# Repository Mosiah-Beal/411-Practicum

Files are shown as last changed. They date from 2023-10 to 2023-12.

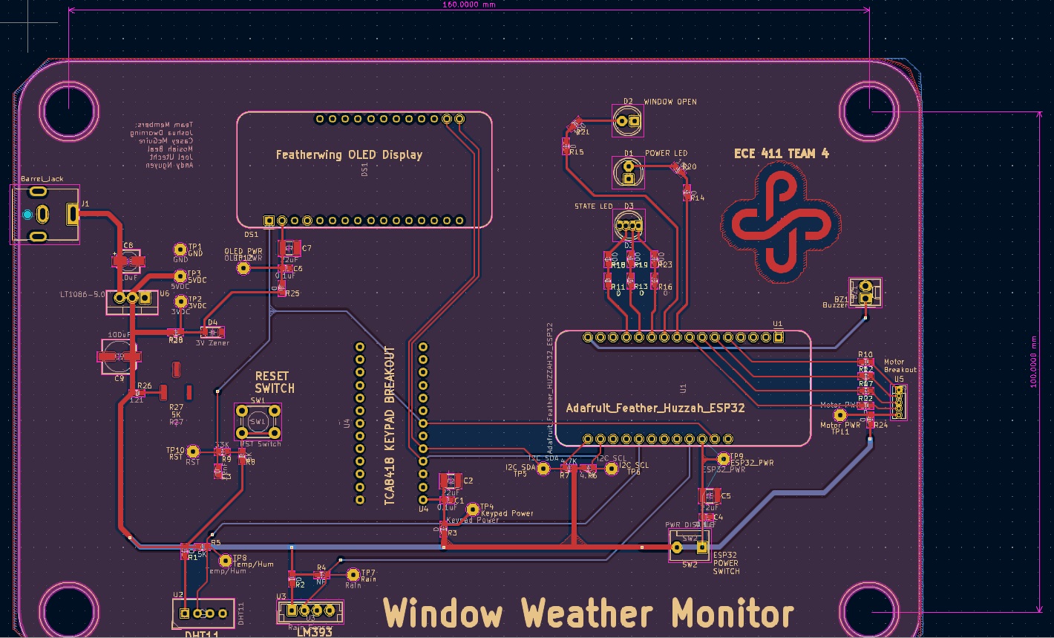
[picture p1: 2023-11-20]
PNG's and PDF's/Schematics and PCBs/PCBA Layout 2D.jpg

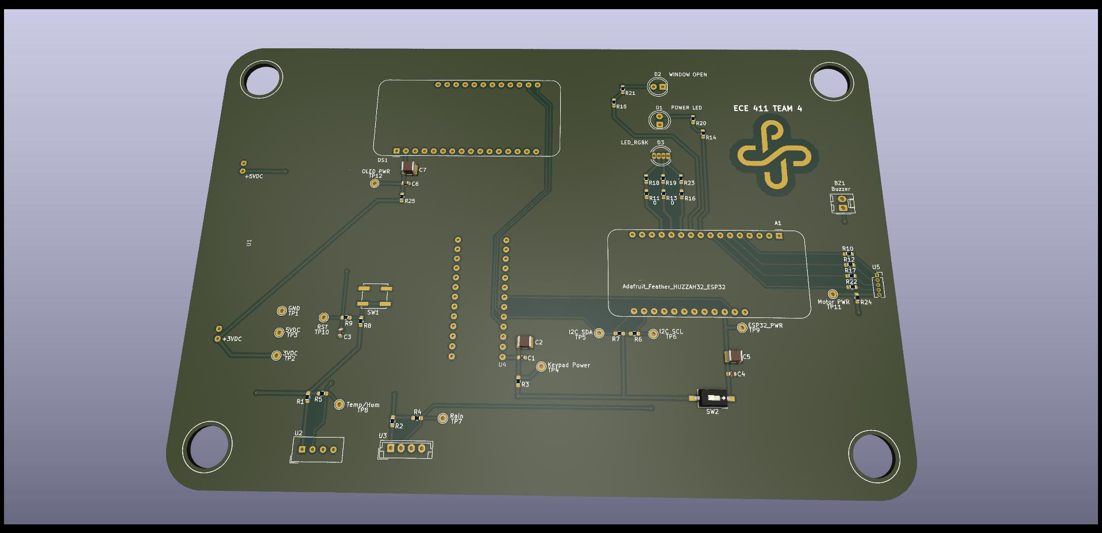
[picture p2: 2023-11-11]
PNG's and PDF's/Schematics and PCBs/window_weather_monitor_pcb.jpg

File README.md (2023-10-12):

# A weather monitor placed near a window
Portland State University Team 4 Practicum Project
Mosiah Beal,	Joshua Dworning,	Andy Nguyen,	Joel Utecht,	Casey McGuire

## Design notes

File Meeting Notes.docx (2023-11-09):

11/8/23

Meeting

Rough bleh of stuff we talked about.

- Question whether D0 Rain Sensor needs pull down or up resistor
- Added C4/C5 as decoupling capacitors on 3.3V Line
- Disconnected A0 of rain sensor from the ESP
- R2 is NP just in case a pull up is needed for D0 of rain sensor
- R1 is a pull up resistor
- R1 is pull up for DHT11 Sensor
- Need schematic to be compatible with DHT22 upgrade
- R15 added as a NP just in case a pull down resistor is needed
- R1 changed into a NP just in case a pull up resistor is needed instead.
- Individual GNDs added to specific pinout on schematic for cleaner look
- Keypad controls uses 4x4 Matrix connected to TCA8418 with communication using I2C
- TCA8418 is Soldered onto PCB
- ESP USB should not be connected when already powered otherwise
- Question whether a switch is needed for USB pin 26 on ESP
- R8/R9 is 0 just in case changes needed to be made
- D3 used to show if window is open
- D1 is LED RGB for environmental state. R G B
- Buzzeer output from ESP pin 16 to Buzzer.
- Question whether a universal RST switch is needed or just specific switch for ESP
- Maybe Display has its own discrete reset button?
  - Confirmed
- I2C/Display/ESP32 RST talk
- RST SW (Pin 7 I2C) global label made for reset
- Motor may need pull resistors. Not known yet. R3,4,5,7,12. Unknown since motor uses digital signals.
- Question whether ADC needs an input
  - Don’t think it matters**
- Layout question of having RESET connected via through hole so that it can jumper to enclosure
- BOM exact details questions asked.
- BOM Spit out by layout is ok.
  - Needs to be reformatted
- Stickers for keypad?
- USING SMD

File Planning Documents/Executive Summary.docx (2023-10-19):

Executive Summary

Problem Statement

Our team recently received feedback from customers in a self-responding poll reporting that they frequently leave their windows open and would like a solution to prevent water damage. The majority responded positively to our proposed product line, and among the price ranges provided, the majority favored a product that would cost no more than $200. Developing the Window Weather Monitor 30K is appropriate in today's market to satisfy this customer demand and increase our existing product lines.

Proposed Solution

The current market ranges up to $300, with most products priced in the $100 to $200 range. Our price point is expected to be $149. To satisfy both customer concerns and allow the company a competitive advantage, our product can offer:

- Sound-based alerts that will attract attention
- Sensors that will monitor for rain conditions and temperature
- A water-resistant enclosure to protect internal electronics
- A display that can report temperature

Final Thoughts and Next Steps

Our product stands out among market competitors because of the portability and more sensors.

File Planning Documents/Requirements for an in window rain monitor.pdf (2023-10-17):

Requirements for an in-window rain monitor.
- The monitor should be able to fit in an open window.
- The monitor should be able to be moved from one window to another.
- The monitor must be able to withstand getting wet from rain.
- The monitor must/should be able to detect when rain is falling on it,
- The monitor must be able to audibly alert the user when rain is detected.
- There must be a method to turn off the alert once it has been activated.
- The monitor should detect temperature.
- It should be able to detect humidity
- The monitor should display the detected temperature.
- The user should be able to manually program a desired temperature range.
- The monitor should be able to sound the audible alert when the detected temperature is outside the designated range.
- Should be able to run of battery power
- The monitor may include the capability of closing the window it is in.
- The monitor may have the capability to be programmed remotely.
- The monitor may have the capability to send alerts to the user’s cell phone.
- The monitor may have the capability to check weather status online.
- May have a rechargeable battery

—----------
- Must have speaker (piezo)
- Must have push buttons to disable alarm
- Must have rain sensor (lm393)
- Should have humidity and temperature sensor (dht11)
- Should have LED/LCD display to show weather condition
- May have stepper motor to ‘move’ window
- May use wifi/bluetooth module of ESP32

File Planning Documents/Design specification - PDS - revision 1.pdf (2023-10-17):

Weather monitor product design specifications
- ESP32 feather microcontroller, or ATmega328P
- Input sensor: DHT11 Temperature and humidity sensor module
- Input sensor: KY-022 IR receiver module
- Input: IR remote control - XIITIA
- Input sensor: LM393 raindrop sensor
- Output: LCD1602 display
- Output: LED
- Output: KY-012 active buzzer
- Output: 1 Motor Driver Board (e.g., Adafruit 2927)
- Output: 1 Stepper Motor (e.g., Amazon B00PNEQKC0)
- Power: USB
- Arduino IDE

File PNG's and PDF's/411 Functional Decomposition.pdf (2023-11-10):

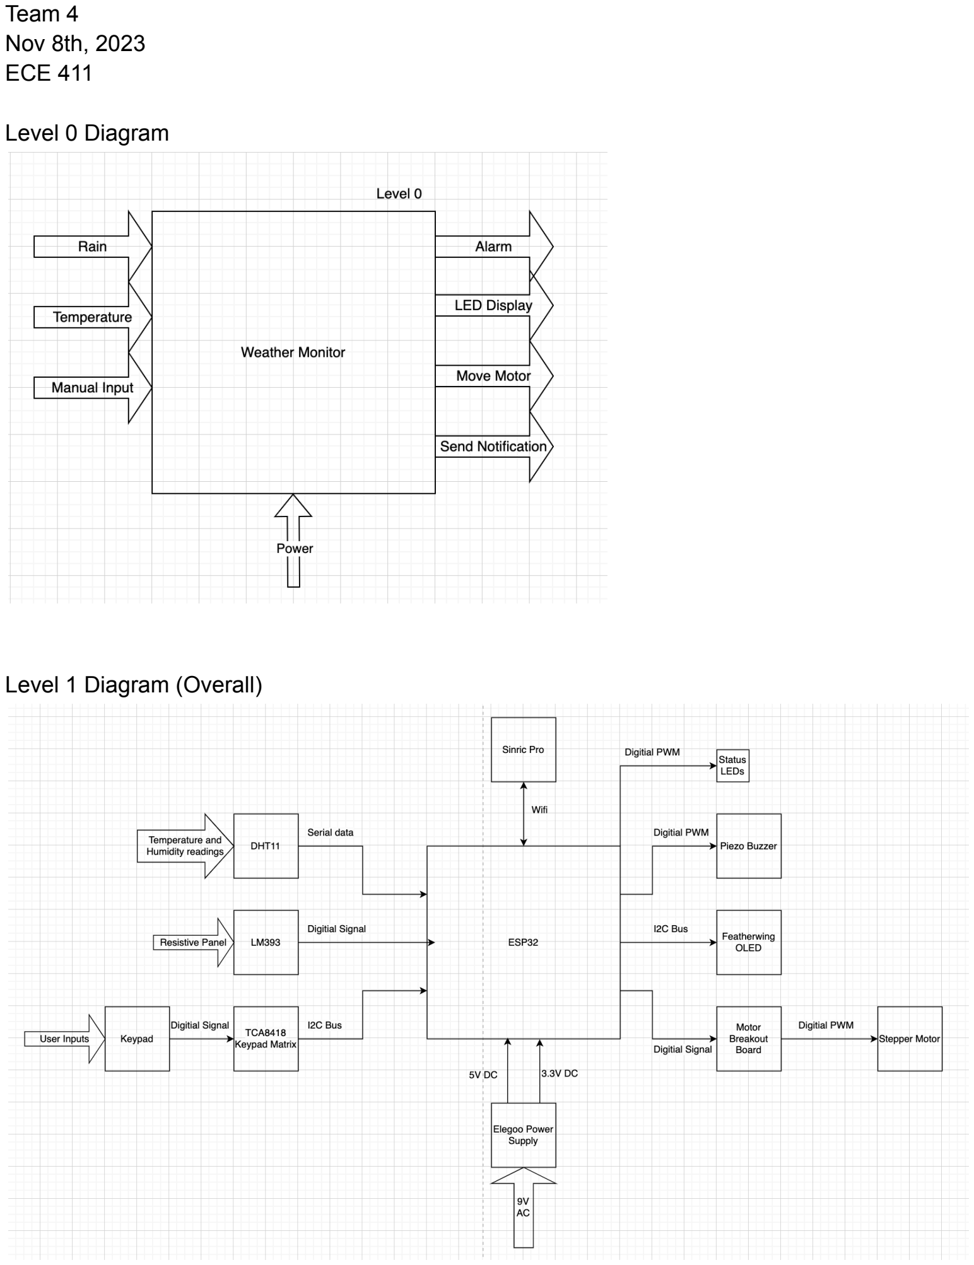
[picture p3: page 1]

Team 4
Nov 8th, 2023
ECE 411

Level 0 Diagram

Level 1 Diagram (Overall)

Power Supply Level 1 Diagram

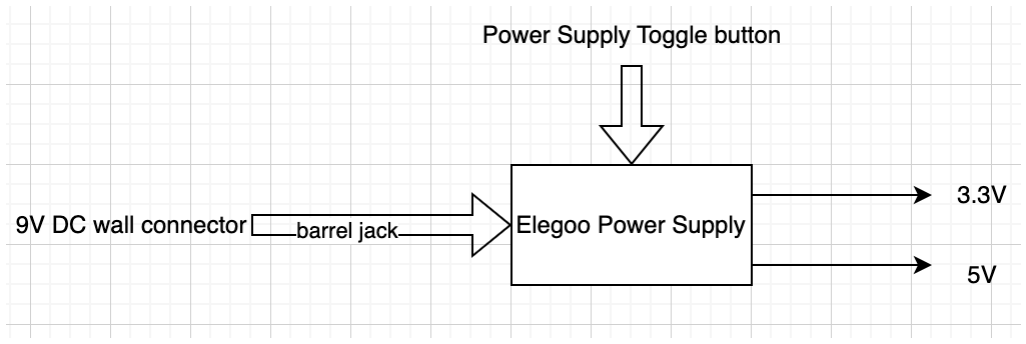
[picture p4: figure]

Module | Power Supply
Inputs | 9V DC: Wall adapter with a barrel jack that is plugged into the power supply Toggle button: A push switch to turn on/off the entire power supply
Outputs | 3.3V DC 5V DC
Functionality | It accepts 6.5-12V DC or USB input and has two independent channels that are configurable to output 3.3V or 5V DC. Can output current up to 700mA.

DHTxx Level 1 Diagram

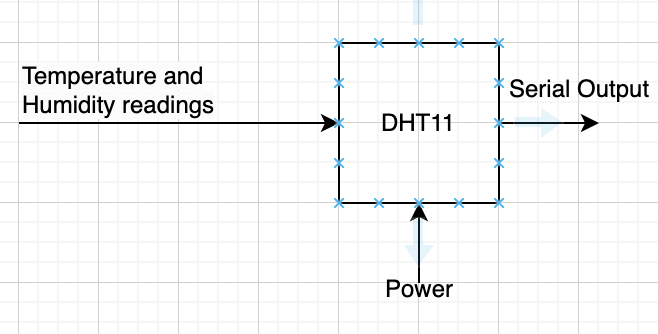
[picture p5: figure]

Module | DHT 11
Inputs | Environmental readings: temperature and humidity levels Power: 5V DC
Outputs | Digital signal: Serial output with a peak of 5V.
Functionality | Measures the temperature and humidity of nearby air, and sends data back through serial communication with the microcontroller. Requires a 5k pullup resistor on the data line.

LM393 / Rain sensor level 1 diagram

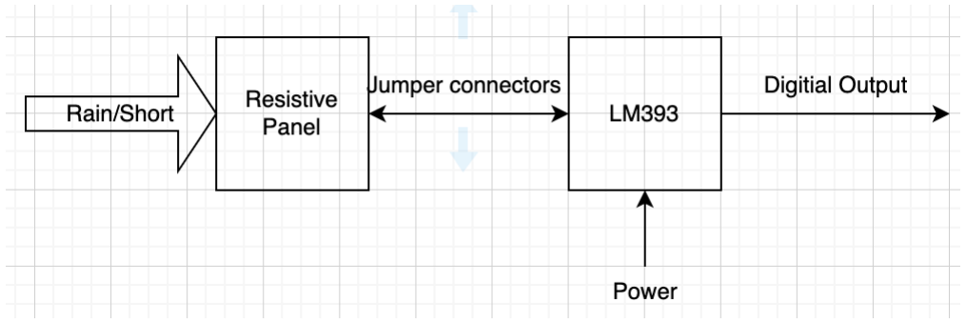
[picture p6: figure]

Module | LM393 + Rain sensor
Inputs | Voltage difference on resistive panel Power: 5V DC Potentiometer: built-in potentiometer that can adjusted to change the sensitivity/transition region of the digital output
Outputs | Digital signal: peak of 3.3V
Functionality | The resistive panel has two strips which are at different voltage levels. When it rains on the panel, a short is created between the strips, decreasing the voltage difference. The LM393 detects this difference and will output a digital signal if it is above a certain threshold. A 0 signifies it is raining while a 1 signifies that it isn’t raining.

Keypad Level 1 Diagram

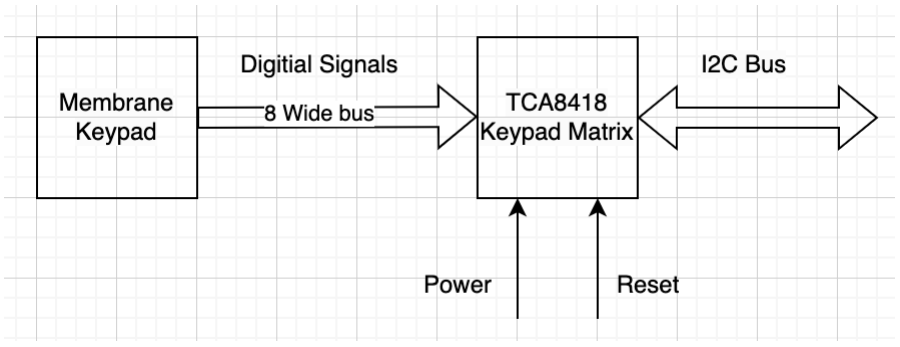
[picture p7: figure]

Module | Keypad Matrix breakout board
Inputs | Digital Signals: the row pins and column pins of the membrane keypad Power: 5V DC Reset switch
Outputs | I2C: Sends data about row and column pins to ESP32
Functionality | Used as a port expander since there were not enough pins available to be allocated to the keypad directly. It sends information about the row and column pins over I2C back to the ESP32. Has built-in 10k pullup resistors on SDA and SCL and is shifted to work with 3-5V logic.

LED Display Level 1 Diagram

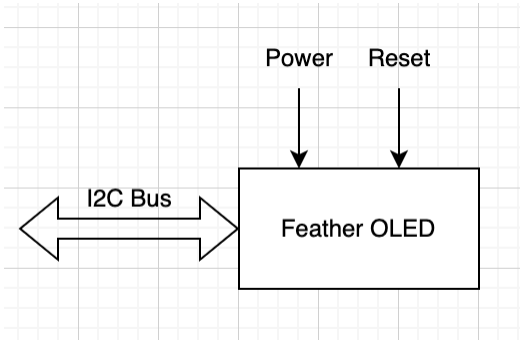
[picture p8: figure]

Module | FeatherWing OLED display
Inputs | I2C bus Reset switch Power: 3.3V DC
Outputs | OLED display updates visually
Functionality | Takes instructions/data from I2C and updates display accordingly. Should display temperature and humidity levels Has 2.2k pullup resistors on SDA and SCL, with 3V logic.

Stepper Motor Level 1 Diagram

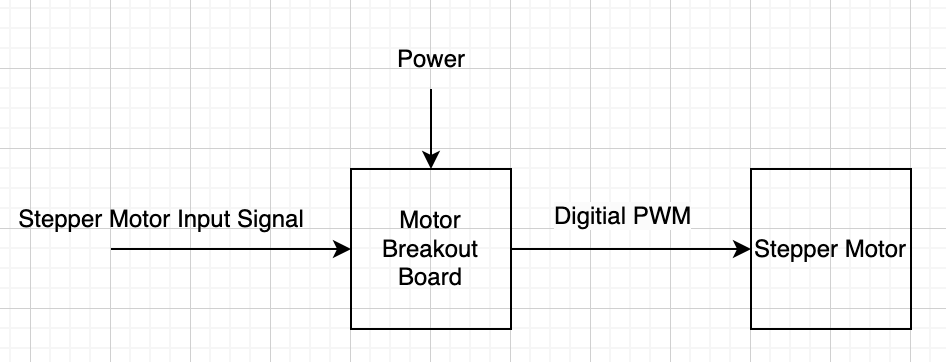
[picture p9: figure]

Module | Stepper motor breakout board
Inputs | Stepper Motor input Signal: digital signal containing the sequence of inputs to make the stepper motor take 1 step. Power: 5V DC
Outputs | Digital PWM: Digital signal which makes the stepper motor take the step
Functionality | The breakout board takes the input signals from the ESP32 and uses them to control the stepper motor. The voltage and current are supplied to the breakout board from the power supply, not the ESP32, which is then delivered to the stepper motor according to the input signals.

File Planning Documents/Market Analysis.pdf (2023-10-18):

The intended customers are people who need a reminder to close the windows during a weather

event.

Product competition for a window weather monitor is saturated. Competitors boast products that

have a motor that will automatically open and close windows and are capable of rain detection.

However, what separates our product from others is the inclusion of temperature and humdity

sensor modules, LED and LCD displays, power via USB, and audible noise alerts.

We could sell this for around $149. The reason for this price is due to the materials cost, labor,

and development. Market conditions for the competition will vary depending on the feature set

that is sought after, but similar products are ranging from $100-$300.

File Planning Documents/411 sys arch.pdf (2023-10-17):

Musts
Sense that it is raining
Sound an alarm

Shoulds
Sense temperature
Have led display status
Have analog input (buttons) for input

Mays
Close the window
Send mobile alerts

—---
Level 0
Ins
Temperature : Analog I/O
Rain : Analog I/O
Programming ESP32: USB cable Power - bullet jack or battery: Analog

Outs
Display: I2C
Buttons : Analog
Speaker alarm : PWM

Maybe:
Phone: wifi/bluetooth
Motor: I2C

—---
Level 1
Temperature, Rain, Buttons, speaker Sensor - does sensing
Sends analog voltage back to processor

Motor and Display : I2C, expand separately

Phone: whatever bluetooth options are chosen

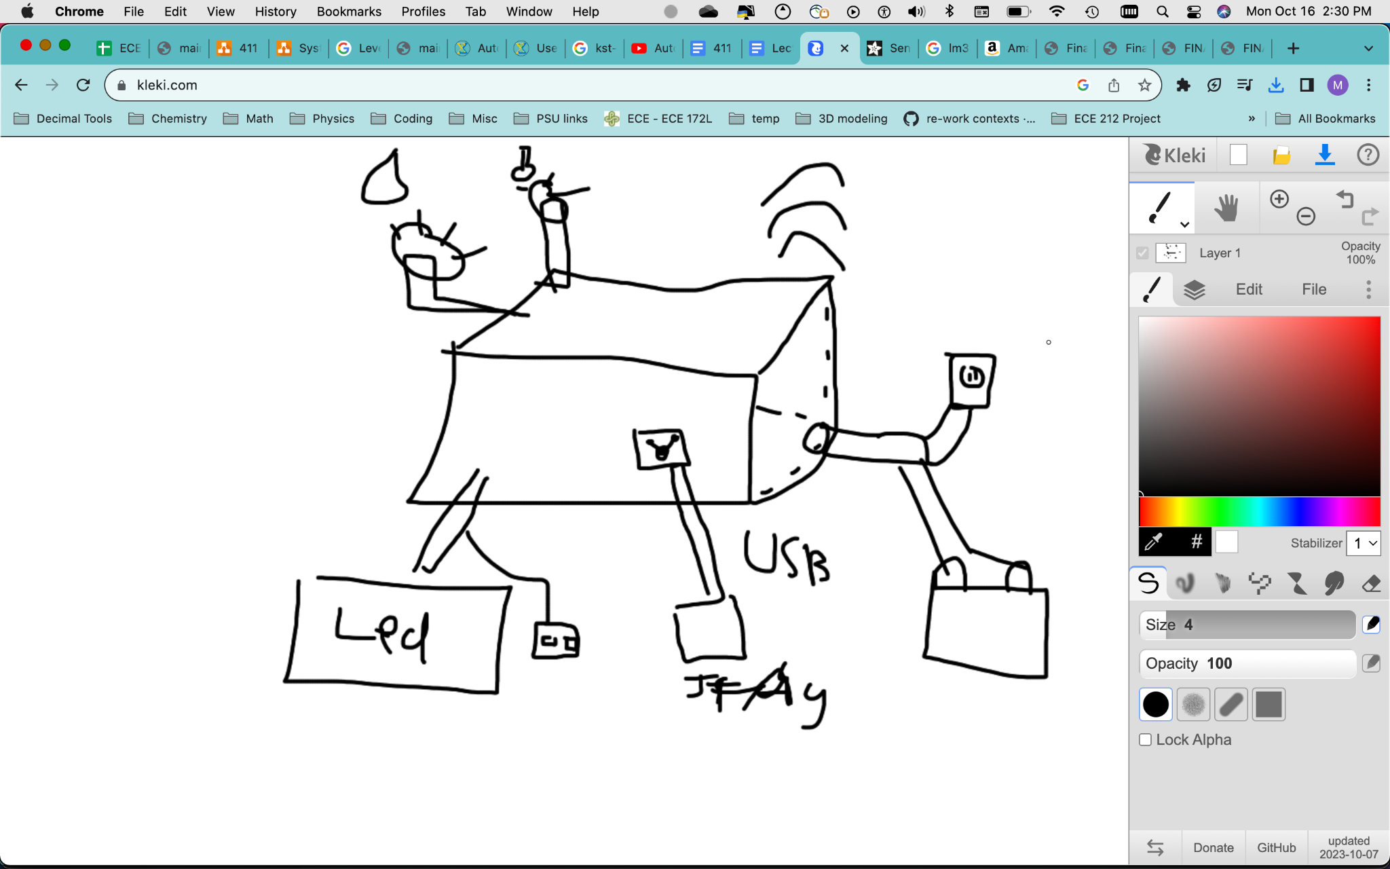
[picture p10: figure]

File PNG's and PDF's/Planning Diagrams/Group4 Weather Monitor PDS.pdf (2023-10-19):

## Executive Summary

### Problem Statement

Our team recently received feedback from customers in a self-responding poll reporting that they frequently leave their windows open and would like a solution to prevent water damage. The majority responded positively to our proposed product line, and among the price ranges provided, the majority favored a product that would cost no more than $200. Developing the Window Weather Monitor 30K is appropriate in today's market to satisfy this customer demand and increase our existing product lines.

### Proposed Solution

The current market ranges up to $300, with most products priced in the $100 to $200 range. Our price point is expected to be $149. To satisfy both customer concerns and allow the company a competitive advantage, our product can offer:
- Sound-based alerts that will attract attention
- Sensors that will monitor for rain conditions and temperature
- A water-resistant enclosure to protect internal electronics
- A display that can report temperature

### Final Thoughts and Next Steps

Our product stands out among market competitors because of the portability and more sensors.

Market:
The intended customers are people who need a reminder to close the windows during a weather event.

Product competition for a window weather monitor is saturated. Competitors boast products that have a motor that will automatically open and close windows and are capable of rain detection. However, what separates our product from others is the inclusion of temperature and humidity sensor modules, LED and LCD displays, power via USB, and audible noise alerts.

We could sell this for around $149. The reason for this price is due to the materials cost, labor, research, and development. Market conditions for the competition will vary depending on the feature set that is sought after, but similar products range from $100-$300.

Requirements:
For our product to meet the needs of our target market it must meet the following criteria. It must be able to detect when it is raining and audibly alert the user when rain is present. There must be a way to manually turn off the audible alert. There should also be a visual alert. The monitor must also be able to withstand repeated exposure to rain.

The monitor should also be able to detect and visually display the current temperature and humidity level. The monitor should allow the user to manually program a desired temperature range and audibly alert the user when the detected temperature is outside the programmed range. The monitor should have an internal power supply that may be rechargeable. The monitor should be able to sit in an open window or be affixed to the exterior near the window. The monitor should be able to be moved from one window to another.
If time and budget allow the monitor may also include some combination of the following features. The monitor may have the capability to close the window it is used in. It may also allow for remote programming and the ability to silence the alerts. It may include connectivity capabilities to monitor weather conditions from an online source and to send window closure alerts to the user's cell phone.

Architecture:

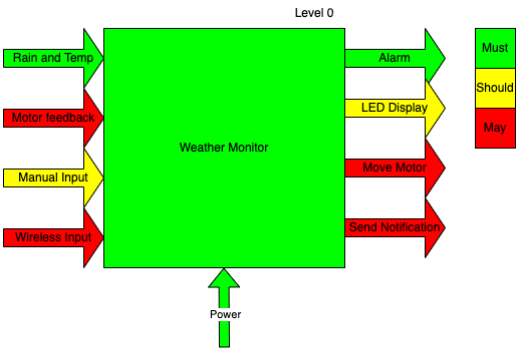
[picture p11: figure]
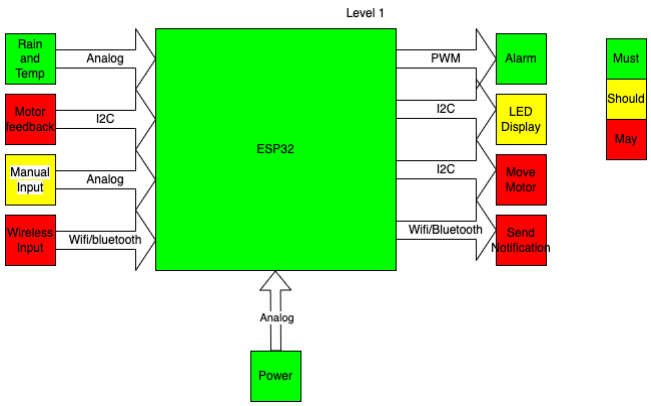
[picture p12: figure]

Design:

Weather monitor product design specifications
- ESP32 feather microcontroller, or ATmega328P
- Input sensor: DHT11 Temperature and humidity sensor module
- Input sensor: KY-022 IR receiver module
- Input: IR remote control - XIITIA
- Input sensor: LM393 raindrop sensor
- Output: LCD1602 display
- Output: LED
- Output: KY-012 active buzzer
- Output: 1 Motor Driver Board (e.g., Adafruit 2927)
- Output: 1 Stepper Motor (e.g., Amazon B00PNEQKC0)
- Power: USB
- Arduino IDE

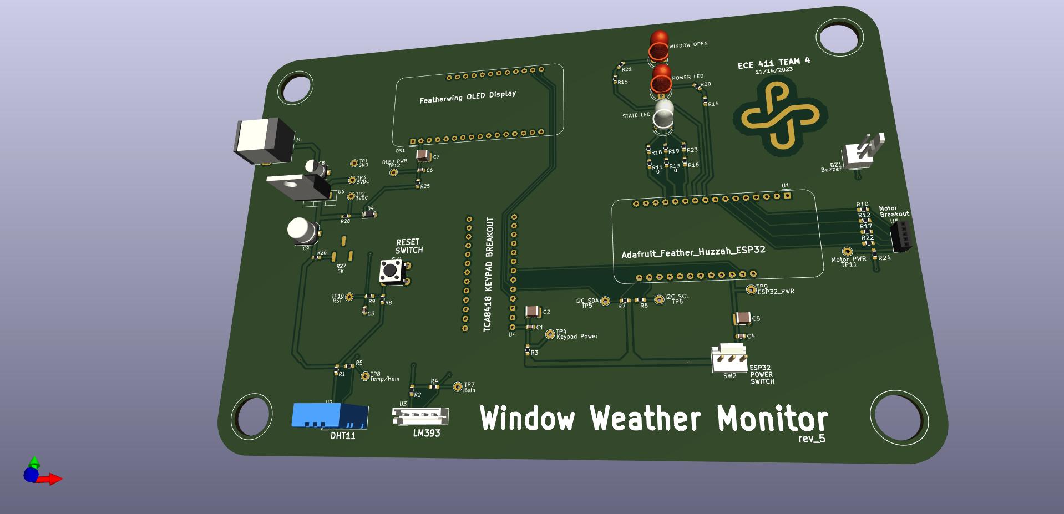
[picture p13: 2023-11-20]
PNG's and PDF's/Schematics and PCBs/PCBA Layout 3D.jpg

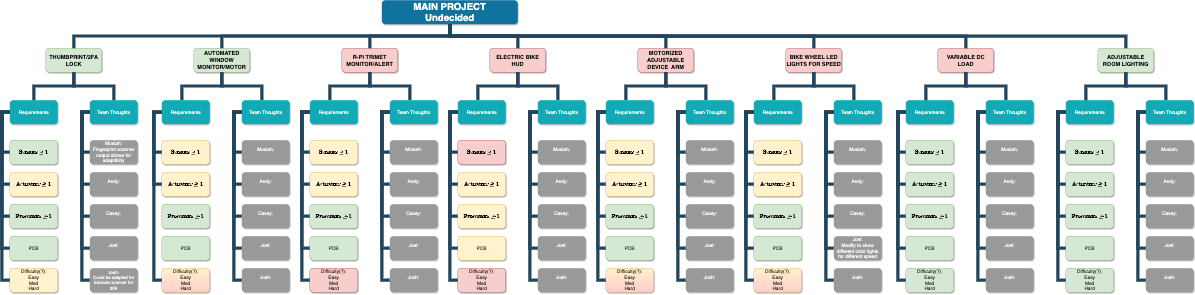
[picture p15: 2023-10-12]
PNG's and PDF's/Planning Diagrams/Zoomed_out_Tree.drawio.png

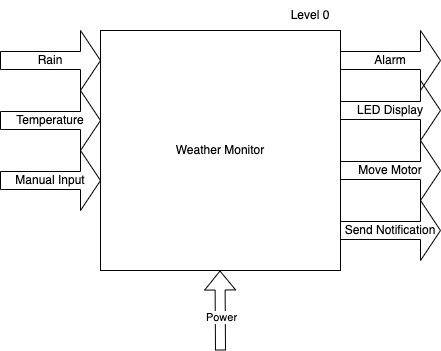
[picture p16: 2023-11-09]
Planning Documents/Level0_Diagram.drawio.png

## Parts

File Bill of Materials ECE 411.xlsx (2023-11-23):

Bill Of Materials for: [TEAM 4] [Window Weather Monitor]
Last modified: [11/8/23]
PCB version: [PCB VERSION #1]
BOM revision: [BOM REVISION #1] |  |  |  | P/NP | = Place/Not Place (components marked NP are not stuffed on the board)
Item | Qty | Part References | Value | P/NP | Mfg | Mfg PN | Description | Dist | Dist Part Number | Cost Ea. | Cost Total | Received (Y/N) | Received QTY
1 | 1 | BZ1 |  | P | Mallory Sonalert | AST1341MCTRQ (https://www.digikey.com/en/products/detail/mallory-sonalert-products-inc/AST1341MCTRQ/11567574) | BUZZER PIEZO 5V 13X13MM SMD | Digi-Key | 458-AST1341MCTRQCT-ND | $2.06 | $2.06 | Y | 3
2 | 3 | C1, C4, C6 | 0.1uF | P | Kemet | C0603C104K8RAC7867 | CAP CER 0.1UF 10V X7R 0603 | Digi-Key | 399-C0603C104K8RAC7867TR-ND (https://www.digikey.com/en/products/detail/kemet/C0603C104K8RAC7867/411094) | $0.10 | $0.20 | N
3 | 3 | C2, C5, C7 | 22uF | P | Samsung | CL32B226KPJVPNE | CAP CER 22UF 10V X7R 1210 | Digi-Key | 1276-CL32B226KPJVPNETR-ND (https://www.digikey.com/en/products/detail/samsung-electro-mechanics/CL32B226KPJVPNE/11487743) | $0.74 | $2.22 | N
4 | 1 | C3 | 0.022uF | P | Wurth Elektronik | 885012206016 | CAP CER 0.022UF 10V X7R 0603 | Digi-Key | 732-7935-2-ND (https://www.digikey.com/en/products/detail/w%C3%BCrth-elektronik/885012206016/5453790) | $0.10 | $0.40 | N
5 | 1 | C8 | 100UF | P | Panasonic | EEE-HA1A101WP | CAP ALUM 100UF 10V | Digi-Key | PCE4169TR-ND (https://www.digikey.com/en/products/detail/panasonic-electronic-components/EEE-HA1A101WP/814141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) | $0.42 | $2.10 | N | 0
6 | 1 | C9 | 10UF | P | Panasonic | EEE-1CA100SR | CAP ALUM 10UF 16V | Digi-Key | PCE3878TR-ND (https://www.digikey.com/en/products/detail/panasonic-electronic-components/EEE-1CA100SR/766045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) | $0.32 | $1.92 | N
7 | 1 | D1 | RED | P | Marktech Optoelectronics | MT4118-HR-A | 5MM LED RED DIFFUSED | Digi-Key | 1125-1188-ND (https://www.digikey.com/en/products/detail/marktech-optoelectronics/MT4118-HR-A/4214622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) | $0.32 | $0.32 | Y | 3
8 | 1 | D2 | GREEN | P | Marktech Optoelectronics | MT2118-G-A | 5MM LED GREEN DIFFUSED | Digi-Key | 1125-1184-ND (https://www.digikey.com/en/products/detail/marktech-optoelectronics/MT2118-G-A/4214619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) | $0.31 | $0.31 | Y | 3
9 | 1 | D3 | RGBK | P | Inolux | HV-5RGB60 | 5MM LED RGBK DIFFUSED | Digi-Key | 1830-1014-ND (https://www.digikey.com/en/products/detail/inolux/HV-5RGB60/7604616?s=N4IgTCBcDaIBIDUC0BWASgcQEIDYAMIAugL5A) | $1.00 | $1.00 | Y | 2
10 | 1 | D4 | 3V | P | Micro Commercial Co | MMSZ4684-TP | DIODE ZENER 3.3V 500MW SOD123 | Digi-Key | MMSZ4684-TPMSTR-ND (https://www.digikey.com/en/products/detail/micro-commercial-co/MMSZ4684-TP/2345538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) | $0.12 | $0.12 | N
11 | 1 | DS1 |  | P | Adafruit | 128x4 OLED | OLED DISPLAY | Adafruit | 2900 (https://www.adafruit.com/product/2900) | $14.95 | $14.95 | Y | 3
12 | 1 | J1 |  | P | CUI Devices | PJ-063AH | CONN PWR BARREL JACK | Digi-Key | CP-063AH-ND (https://www.digikey.com/en/products/detail/cui-devices/PJ-063AH/2161208?s=N4IgTCBcDaIAoCkC0AGAbAZgIIAkQF0BfIA) | $1.55 | $1.55 | Y | 5
13 | 1 | K1 |  | P | Parallax | 4X4MEMKYPD | 4X4 MEMBRANE KEYPAD | Parallax | 27899 (https://www.parallax.com/product/4x4-matrix-membrane-keypad/) | $9.95 | $9.95 | Y | 2
14 | 14 | R1, R2, R3, R10, R11, R12, R13, R14, R15, R16, R17, R22, R24, R25 | 0 Ohm | P | Stackpole Elec. Inc. | RMCF0603ZT0R00 | RES 0 OHM JUMPER 1/10W 0603 | Digi-Key | RMCF0603ZT0R00TR-ND (https://www.digikey.com/en/products/detail/stackpole-electronics-inc/RMCF0603ZT0R00/1756908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) | $0.10 | $1.40 | N
15 | 1 | R4 | 5K Ohm | NP | Yageo | RT0603BRE075KL | RES 5K OHM 1/10W 0603 | Digi-Key | 13-RT0603BRE075KLTR-ND (https://www.digikey.com/en/products/detail/yageo/RT0603BRE075KL/7708365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) | $0.39 | $0.39 | N
16 | 2 | R5, R8 | 5K Ohm | P | Yageo | RT0603BRE075KL | RES 5K OHM 1/10W 0603 | Digi-Key | 13-RT0603BRE075KLTR-ND (https://www.digikey.com/en/products/detail/yageo/RT0603BRE075KL/7708365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) | $0.39 | $0.78 | N
17 | 2 | R6, R7 | 4.7 kOhm | P | KOA Speer Electronics | RK73B1JTTD472J | RES 4.7K OHM 1/10W 0603 | Digi-Key | 2019-RK73B1JTTD472JTR-ND (https://www.digikey.com/en/products/detail/koa-speer-electronics-inc/RK73B1JTTD472J/9844699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) | $0.10 | $0.20 | N
18 | 1 | R9 | 33 kOhm | P | Stackpole Elec. Inc. | RMCF0603FT33K0 | RES 33K OHM 1/10W 0603 | Digi-Key | RMCF0603FT33K0TR-ND (https://www.digikey.com/en/products/detail/stackpole-electronics-inc/RMCF0603FT33K0/1760742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) | $0.10 | $0.10 | N
19 | 5 | R18, R19, R20, R21, R23 | 100 Ohm | P | Stackpole Elec. Inc. | RMCF0603FT100R | RES 100 OHM 1/10W 0603 | Digi-Key | RMCF0603FT100RTR-ND (https://www.digikey.com/en/products/detail/stackpole-electronics-inc/RMCF0603FT100R/1761113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) | $0.10 | $0.50 | N
20 | 1 | R26 | 121 Ohm | P | Stackpole Elec. Inc. | RMCF0603FT121R | RES 121 OHM 1/10W 0603 | Digi-Key | RMCF0603FT121RTR-ND (https://www.digikey.com/en/products/detail/stackpole-electronics-inc/RMCF0603FT121R/1761217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) | $0.10 | $0.10 | N
21 | 1 | R27 | 5 kOHM | P | TT Electronics | 84WR5KLFTR | TRIMMER 5K OHM 0.25W SMD | Digi-Key | 987-1810-2-ND (https://www.digikey.com/en/products/detail/tt-electronics-bi/84WR5KLFTR/6155682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) | $3.36 | $3.36 | N
22 | 1 | R28 | 430 Ohm | P | Stackpole Elec. Inc. | RMCF0603FT430R | RES 430 OHM 1/10W 0603 | Digi-Key | RMCF0603FT430RTR-ND (https://www.digikey.com/en/products/detail/stackpole-electronics-inc/RMCF0603FT430R/1761190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) | $0.10 | $0.10 | N
23 | 1 | SW1 |  | P | DAOKI | SPST THT SW | 6MM MOMENTARY SWITCH THT | Amazon | DAOKITHTPB (https://www.amazon.com/DAOKI-Miniature-Momentary-Tactile-Quality/dp/B01CGMP9GY?hvadid=80676721524207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) | $0.05 | $0.05 | Y | 5
24 | 1 | SW2 |  | P | C&K | TS02CQE | SWITCH SLIDE SPST 1A 120V | Digi-Key | CKN10666-ND (https://www.digikey.com/en/products/detail/c-k/TS02CQE/3755397?s=N4IgTCBcDaICoGUAMYDCBFAoiAugXyA) | $7.76 | $7.76 | Y | 100
25 | 1 | U1 |  | P | Adafruit | ESP32-HUZZAH | Adafruit ESP32 Huzzah Feather Board | Adafruit | 3405 (https://www.adafruit.com/product/3405) | $19.95 | $19.95 | Y | 2
26 | 1 | U2 |  | P | Adafruit | DHT22 | TEMP/HUM SENSOR | Adafruit | 385 (https://www.adafruit.com/product/385) | $9.95 | $9.95 | Y | 2
27 | 1 | U3 |  | P | HiLetgo | LM393 | LM393 MOISTURE SENSOR | Amazon | HILETGO-LM393 | $2.20 | $2.20 | Y | 4
28 | 1 | U4 |  | P | Adafruit | TCA8418 | KEYPAD EXANDER BREAKOUT | Adafruit | 4918 (https://www.adafruit.com/product/4918) | $5.95 | $5.95 | Y | 3
29 | 1 | U5 |  | P | ULN | ULN2003 | STEPPER MOTOR DRIVE BREAKOUT | Amazon | ULN2003 (https://www.amazon.com/ULN2003-Controller-Stepping-Electric-Control/dp/B07P5C2KWX) | $2.30 | $2.30 | Y | 1
30 | 1 | U6 |  | P | Analog Devices | LT1086CT#PBF | IC REG LIN POS ADJ 1.5A TO220-3 | Digi-Key | 505-LT1086CT#PBF-ND (https://www.digikey.com/en/products/detail/analog-devices-inc/LT1086CT-PBF/891238) | $6.29 | $6.29 | Y | 5
 |  |  |  |  |  |  |  |  |  | TOTAL: | $98.48
VERSION INFO
Rev |  | Date |  | Notes
1.0r0 |  | 2023-11-07 |  | Initial BOM. Not everything chosen but mostly there.
2.0r0 |  | 2023-11-13 |  | Updated BOM. Almost everything chosen.
2.0r1 |  | 2023-11-22 |  | Updated BOM to add part values where applicable. Also added received section.

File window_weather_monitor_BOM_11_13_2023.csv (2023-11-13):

Source: | C:\Users\jdworning\Documents\KiCad\ECE411_Practicum\window_weather_monitor\window_weather_monitor.kicad_sch
Date: | 11/13/2023 11:16:47 AM
Tool: | Eeschema 7.0.8
Generator: | C:\Program Files\KiCad\7.0\bin\scripting\plugins/bom_csv_grouped_by_value.py
Component Count: | 65
Collated Components:
Item | Qty | Reference(s) | Value | LibPart | Footprint | Datasheet | DNP | Color | MFG PN | Notes | Part Link | Pinout
1 | 1 | BZ1 | Buzzer | Device:Buzzer | Connector_Molex:Molex_KK-254_AE-6410-02A_1x02_P2.54mm_Vertical | ~ |  |  | N/A
2 | 3 | C1, C4, C6 | 0.1uF | Device:C_Small | Capacitor_SMD:C_0603_1608Metric | ~ |  |  | C0603C104K8RAC7867 |  | https://www.digikey.com/en/products/detail/kemet/C0603C104K8RAC7867/411094
3 | 3 | C2, C5, C7 | 22uF | Device:C_Small | Capacitor_SMD:C_1210_3225Metric | ~ |  |  | CL32B226KPJVPNE |  | https://www.digikey.com/en/products/detail/samsung-electro-mechanics/CL32B226KPJVPNE/11487743
4 | 1 | C3 | 22nF | Device:C_Small | Capacitor_SMD:C_0603_1608Metric | ~ |  |  | CL05B223KP5NNNC |  | https://www.digikey.com/en/products/detail/samsung-electro-mechanics/CL05B223KP5NNNC/3887196
5 | 1 | C8 | 10uF | Device:C_Polarized_Small_US | Capacitor_SMD:CP_Elec_4x5.4 | ~ |  |  | EEE-HA1A101WP |  | https://www.digikey.com/en/products/detail/panasonic-electronic-components/EEE-HA1A101WP/814141
6 | 1 | C9 | 100uF | Device:C_Polarized_Small_US | Capacitor_SMD:C_Elec_6.3x5.8 | ~ |  |  | EEE-1CA100SR |  | https://www.digikey.com/en/products/detail/panasonic-electronic-components/EEE-1CA100SR/766045
7 | 1 | D1 | POWER LED | Device:LED | LED_THT:LED_D5.0mm | ~ |  | RED | MT4118-HR-A |  | https://www.digikey.com/en/products/detail/marktech-optoelectronics/MT4118-HR-A/4214622
8 | 1 | D2 | WINDOW OPEN | Device:LED | LED_THT:LED_D5.0mm | ~ |  |  | MT2118-G-A |  | https://www.digikey.com/en/products/detail/marktech-optoelectronics/MT2118-G-A/4214619
9 | 1 | D3 | LED_RGBK | Device:LED_RGBK | LED_THT:LED_D5.0mm-4_RGB | ~ |  |  | HV-5RGB60 |  | https://www.digikey.com/en/products/detail/inolux/HV-5RGB60/7604616
10 | 1 | D4 | 3V Zener | Device:D_Zener | Diode_SMD:D_SOD-123 | ~ |  |  | MMSZ4684-TP |  | https://www.digikey.com/en/products/detail/micro-commercial-co/MMSZ4684-TP/2345538
11 | 1 | DS1 | ~ | my_library:Display-OLED-FeatherWing | Module:Adafruit_Feather |  |  |  | 128x4 OLED
12 | 1 | J1 | Barrel_Jack | Connector:Barrel_Jack | Connector_BarrelJack:BarrelJack_CUI_PJ-063AH_Horizontal | ~ |  |  | PJ-063AH |  | https://www.digikey.com/en/products/detail/cui-devices/PJ-063AH/2161208
13 | 1 | K1 | 4x4_Matrix_Keypad | my_library:4x4_Matrix_Keypad
14 | 14 | R1, R2, R3, R10, R11, R12, R13, R14, R15, R16, R17, R22, R24, R25 | 0 | Device:R | Resistor_SMD:R_0603_1608Metric_Pad0.98x0.95mm_HandSolder | ~ |  |  | RMCF0603ZT0R00 |  | https://www.digikey.com/en/products/detail/stackpole-electronics-inc/RMCF0603ZT0R00/1756908
15 | 1 | R4 | NP | Device:R | Resistor_SMD:R_0603_1608Metric_Pad0.98x0.95mm_HandSolder | ~ |  |  | RMCF0603ZT0R00 |  | https://www.digikey.com/en/products/detail/stackpole-electronics-inc/RMCF0603ZT0R00/1756908
16 | 2 | R5, R8 | 5K | Device:R | Resistor_SMD:R_0603_1608Metric_Pad0.98x0.95mm_HandSolder | ~ |  |  | RT0603BRE075KL | 5K | https://www.digikey.com/en/products/detail/yageo/RT0603BRE075KL/7708365
17 | 2 | R6, R7 | 4.7K | Device:R | Resistor_SMD:R_0603_1608Metric_Pad0.98x0.95mm_HandSolder | ~ |  |  | RK73B1JTTD472J | 4.7K | https://www.digikey.com/en/products/detail/koa-speer-electronics-inc/RK73B1JTTD472J/9844699
18 | 1 | R9 | 33K | Device:R | Resistor_SMD:R_0603_1608Metric_Pad0.98x0.95mm_HandSolder | ~ |  |  | RMCF0603FT33K0 |  | https://www.digikey.com/en/products/detail/stackpole-electronics-inc/RMCF0603FT33K0/1760742
19 | 5 | R18, R19, R20, R21, R23 | 100 | Device:R | Resistor_SMD:R_0603_1608Metric_Pad0.98x0.95mm_HandSolder | ~ |  |  | RMCF0603FT100R |  | https://www.digikey.com/en/products/detail/stackpole-electronics-inc/RMCF0603FT100R/1761113
20 | 1 | R26 | 121 | Device:R | Resistor_SMD:R_0603_1608Metric_Pad0.98x0.95mm_HandSolder | ~ |  |  | RMCF0603FT121R |  | https://www.digikey.com/en/products/detail/stackpole-electronics-inc/RMCF0603FT121R/1761217
21 | 1 | R27 | 5K | Device:R_Variable | my_library:5K Trim Pot | ~ |  |  | 84WR5KLFTR |  | https://www.digikey.com/en/products/detail/tt-electronics-bi/84WR5KLFTR/6155682
22 | 1 | R28 | 430 | Device:R | Resistor_SMD:R_0603_1608Metric_Pad0.98x0.95mm_HandSolder | ~ |  |  | RMCF0603FT430R |  | https://www.digikey.com/en/products/detail/stackpole-electronics-inc/RMCF0603FT430R/1761190
23 | 1 | SW1 | RST Switch | Switch:SW_Push | Button_Switch_THT:SW_PUSH_6mm | ~ |  |  | DAOKI SPST |  | https://www.amazon.com/DAOKI-Miniature-Momentary-Tactile-Quality/dp/B01CGMP9GY?hvadid=80676721524207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
24 | 1 | SW2 | PWR DISABLE | Switch:SW_SPST | Connector:FanPinHeader_1x03_P2.54mm_Vertical | ~ |  |  | TS02CQE |  | https://www.digikey.com/en/products/detail/c-k/TS02CQE/3755397
25 | 1 | TP1 | GND | Connector:TestPoint_Small | my_library:TestPoint_THTPad_D2.0mm_Drill1.0mm | ~
26 | 1 | TP2 | 3VDC | Connector:TestPoint_Small | my_library:TestPoint_THTPad_D2.0mm_Drill1.0mm | ~
27 | 1 | TP3 | 5VDC | Connector:TestPoint_Small | my_library:TestPoint_THTPad_D2.0mm_Drill1.0mm | ~
28 | 1 | TP4 | Keypad Power | Connector:TestPoint_Small | my_library:TestPoint_THTPad_D2.0mm_Drill1.0mm | ~
29 | 1 | TP5 | I2C SDA | Connector:TestPoint_Small | my_library:TestPoint_THTPad_D2.0mm_Drill1.0mm | ~
30 | 1 | TP6 | I2C SCL | Connector:TestPoint_Small | my_library:TestPoint_THTPad_D2.0mm_Drill1.0mm | ~
31 | 1 | TP7 | Rain | Connector:TestPoint_Small | my_library:TestPoint_THTPad_D2.0mm_Drill1.0mm | ~
32 | 1 | TP8 | Temp/Hum | Connector:TestPoint_Small | my_library:TestPoint_THTPad_D2.0mm_Drill1.0mm | ~
33 | 1 | TP9 | ESP32_PWR | Connector:TestPoint_Small | my_library:TestPoint_THTPad_D2.0mm_Drill1.0mm | ~
34 | 1 | TP10 | RST | Connector:TestPoint_Small | my_library:TestPoint_THTPad_D2.0mm_Drill1.0mm | ~
35 | 1 | TP11 | Motor PWR | Connector:TestPoint_Small | my_library:TestPoint_THTPad_D2.0mm_Drill1.0mm | ~
36 | 1 | TP12 | OLED PWR | Connector:TestPoint_Small | my_library:TestPoint_THTPad_D2.0mm_Drill1.0mm | ~
37 | 1 | U1 | Adafruit_Feather_HUZZAH32_ESP32 | MCU_Module:Adafruit_Feather_HUZZAH32_ESP32 | Module:Adafruit_Feather | https://cdn-learn.adafruit.com/downloads/pdf/adafruit-huzzah32-esp32-feather.pdf
38 | 1 | U2 | DHT11 | Sensor:DHT11 | Sensor:Aosong_DHT11_5.5x12.0_P2.54mm | http://akizukidenshi.com/download/ds/aosong/DHT11.pdf |  |  |  |  |  | S. -> P1
39 | 1 | U3 | Rain Sensor | my_library:LM393_Rain_Sensor | Connector_JST:JST_EH_B4B-EH-A_1x04_P2.50mm_Vertical | ~
40 | 1 | U4 | ~ | my_library:TCA8418_Keypad_/_GPIO_Extension | my_library:TCA8418
41 | 1 | U5 | ~ | my_library:Motor_Control_IO | Connector_PinSocket_1.27mm:PinSocket_1x05_P1.27mm_Vertical
42 | 1 | U6 | LT1086-5.0 | Regulator_Linear:LT1086-5.0 | Package_TO_SOT_THT:TO-220-3_Vertical | https://www.analog.com/media/en/technical-documentation/data-sheets/1086ffs.pdf |  |  | LT1086CT#PBF |  | https://www.digikey.com/en/products/detail/analog-devices-inc/LT1086CT-PBF/891238

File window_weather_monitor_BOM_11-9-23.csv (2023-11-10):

Source: | C:\Users\jdworning\Documents\KiCad\ECE411_Practicum\window_weather_monitor\window_weather_monitor.kicad_sch
Date: | 11/9/2023 11:33:07 PM
Tool: | Eeschema 7.0.8
Generator: | C:\Program Files\KiCad\7.0\bin\scripting\plugins/bom_csv_grouped_by_value.py
Component Count: | 58
Collated Components:
Item | Qty | Reference(s) | Value | LibPart | Footprint | Datasheet | DNP | Color | MFG PN | Notes | Part Link | Pinout
1 | 1 | A1 | Adafruit_Feather_HUZZAH32_ESP32 | MCU_Module:Adafruit_Feather_HUZZAH32_ESP32 | Module:Adafruit_Feather | https://cdn-learn.adafruit.com/downloads/pdf/adafruit-huzzah32-esp32-feather.pdf
2 | 1 | BZ1 | Buzzer | Device:Buzzer | Connector_Molex:Molex_KK-254_AE-6410-02A_1x02_P2.54mm_Vertical | ~
3 | 3 | C1, C4, C6 | 0.1uF | Device:C_Small | Capacitor_SMD:C_0603_1608Metric | ~ |  |  | C0603C104K8RAC7867 |  | https://www.digikey.com/en/products/detail/kemet/C0603C104K8RAC7867/411094
4 | 3 | C2, C5, C7 | 22uF | Device:C_Small | Capacitor_SMD:C_1210_3225Metric | ~ |  |  | CL32B226KPJVPNE |  | https://www.digikey.com/en/products/detail/samsung-electro-mechanics/CL32B226KPJVPNE/11487743
5 | 1 | C3 | 22nF | Device:C_Small | Capacitor_SMD:C_0603_1608Metric | ~ |  |  | CL05B223KP5NNNC |  | https://www.digikey.com/en/products/detail/samsung-electro-mechanics/CL05B223KP5NNNC/3887196
6 | 1 | D1 | POWER LED | Device:LED | LED_THT:LED_D5.0mm | ~ |  | RED | MT4118-HR-A |  | https://www.digikey.com/en/products/detail/marktech-optoelectronics/MT4118-HR-A/4214622
7 | 1 | D2 | WINDOW OPEN | Device:LED | LED_THT:LED_D5.0mm | ~ |  |  | MT2118-G-A |  | https://www.digikey.com/en/products/detail/marktech-optoelectronics/MT2118-G-A/4214619
8 | 1 | D3 | LED_RGBK | Device:LED_RGBK | LED_THT:LED_D5.0mm-4_RGB | ~ |  |  | HV-5RGB60 |  | https://www.digikey.com/en/products/detail/inolux/HV-5RGB60/7604616
9 | 1 | DS1 | ~ | my_library:Display-OLED-FeatherWing | Module:Adafruit_Feather
10 | 1 | K1 | 4x4_Matrix_Keypad | my_library:4x4_Matrix_Keypad
11 | 14 | R1, R2, R3, R10, R11, R12, R13, R14, R15, R16, R17, R22, R24, R25 | 0 | Device:R | Resistor_SMD:R_0603_1608Metric_Pad0.98x0.95mm_HandSolder | ~ |  |  | RMCF0603ZT0R00 |  | https://www.digikey.com/en/products/detail/stackpole-electronics-inc/RMCF0603ZT0R00/1756908
12 | 1 | R4 | NP | Device:R | Resistor_SMD:R_0603_1608Metric_Pad0.98x0.95mm_HandSolder | ~ |  |  | RMCF0603ZT0R00 |  | https://www.digikey.com/en/products/detail/stackpole-electronics-inc/RMCF0603ZT0R00/1756908
13 | 2 | R5, R8 | 5K | Device:R | Resistor_SMD:R_0603_1608Metric_Pad0.98x0.95mm_HandSolder | ~ |  |  | RT0603BRE075KL | 5K | https://www.digikey.com/en/products/detail/yageo/RT0603BRE075KL/7708365
14 | 2 | R6, R7 | 4.7K | Device:R | Resistor_SMD:R_0603_1608Metric_Pad0.98x0.95mm_HandSolder | ~ |  |  | RK73B1JTTD472J | 4.7K | https://www.digikey.com/en/products/detail/koa-speer-electronics-inc/RK73B1JTTD472J/9844699
15 | 1 | R9 | 33K | Device:R | Resistor_SMD:R_0603_1608Metric_Pad0.98x0.95mm_HandSolder | ~ |  |  | RMCF0603FT33K0 |  | https://www.digikey.com/en/products/detail/stackpole-electronics-inc/RMCF0603FT33K0/1760742
16 | 5 | R18, R19, R20, R21, R23 | 100 | Device:R | Resistor_SMD:R_0603_1608Metric_Pad0.98x0.95mm_HandSolder | ~ |  |  | RMCF0603FT100R |  | https://www.digikey.com/en/products/detail/stackpole-electronics-inc/RMCF0603FT100R/1761113
17 | 1 | SW1 | RST Switch | Switch:SW_Push | Button_Switch_SMD:SW_Push_1P1T_NO_CK_KSC6xxJ | ~
18 | 1 | SW2 | PWR DISABLE | Switch:SW_SPST | Button_Switch_SMD:SW_DIP_SPSTx01_Slide_6.7x4.1mm_W8.61mm_P2.54mm_LowProfile | ~ |  |  | TS02CQE |  | https://www.digikey.com/en/products/detail/c-k/TS02CQE/3755397
19 | 1 | TP1 | GND | Connector:TestPoint_Small | my_library:TestPoint_THTPad_D2.0mm_Drill1.0mm | ~
20 | 1 | TP2 | 3VDC | Connector:TestPoint_Small | my_library:TestPoint_THTPad_D2.0mm_Drill1.0mm | ~
21 | 1 | TP3 | 5VDC | Connector:TestPoint_Small | my_library:TestPoint_THTPad_D2.0mm_Drill1.0mm | ~
22 | 1 | TP4 | Keypad Power | Connector:TestPoint_Small | my_library:TestPoint_THTPad_D2.0mm_Drill1.0mm | ~
23 | 1 | TP5 | I2C SDA | Connector:TestPoint_Small | my_library:TestPoint_THTPad_D2.0mm_Drill1.0mm | ~
24 | 1 | TP6 | I2C SCL | Connector:TestPoint_Small | my_library:TestPoint_THTPad_D2.0mm_Drill1.0mm | ~
25 | 1 | TP7 | Rain | Connector:TestPoint_Small | my_library:TestPoint_THTPad_D2.0mm_Drill1.0mm | ~
26 | 1 | TP8 | Temp/Hum | Connector:TestPoint_Small | my_library:TestPoint_THTPad_D2.0mm_Drill1.0mm | ~
27 | 1 | TP9 | ESP32_PWR | Connector:TestPoint_Small | my_library:TestPoint_THTPad_D2.0mm_Drill1.0mm | ~
28 | 1 | TP10 | RST | Connector:TestPoint_Small | my_library:TestPoint_THTPad_D2.0mm_Drill1.0mm | ~
29 | 1 | TP11 | Motor PWR | Connector:TestPoint_Small | my_library:TestPoint_THTPad_D2.0mm_Drill1.0mm | ~
30 | 1 | TP12 | OLED PWR | Connector:TestPoint_Small | my_library:TestPoint_THTPad_D2.0mm_Drill1.0mm | ~
31 | 1 | U1 | ~ | my_library:Elegoo_MB_V2 | my_library:Elegoo MB V2
32 | 1 | U2 | DHT11 | Sensor:DHT11 | Sensor:Aosong_DHT11_5.5x12.0_P2.54mm | http://akizukidenshi.com/download/ds/aosong/DHT11.pdf |  |  |  |  |  | S. -> P1
33 | 1 | U3 | Rain Sensor | my_library:LM393_Rain_Sensor | Connector_JST:JST_EH_B4B-EH-A_1x04_P2.50mm_Vertical | ~
34 | 1 | U4 | ~ | my_library:TCA8418_Keypad_/_GPIO_Extension | my_library:TCA8418
35 | 1 | U5 | ~ | my_library:Motor_Control_IO | Connector_PinSocket_1.27mm:PinSocket_1x05_P1.27mm_Vertical

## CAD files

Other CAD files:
PNG's and PDF's/Planning Diagrams/ONELINE_DIAGRAM.dwg

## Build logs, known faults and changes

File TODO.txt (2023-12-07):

TODO:
    [OLED]
        Use monitor.display flag to send output to OLED or Serial respectively (for all print messages)
        Get a graph of temperature/humid, print current temp/humid
        Give dedicated line to printing messages to user

    [MENU]
        Add shutdown function
        Add settings view/reset option
        Add toggle to view only readings/graph (cancel on keypad input)
        Show keypresses in live time when entering new values.

    [LOOP]
        Refactor handle functions to work independently and not take control from each other
        The goal is to have most of handlers work silently in background updating variables

    [General]
        Add Debugging levels to suppress output
        Test functions should be only for tests, make new ones for serial version or add if-else to pre-existing code
        Update component connection statuses on loop (unplug/insert components)

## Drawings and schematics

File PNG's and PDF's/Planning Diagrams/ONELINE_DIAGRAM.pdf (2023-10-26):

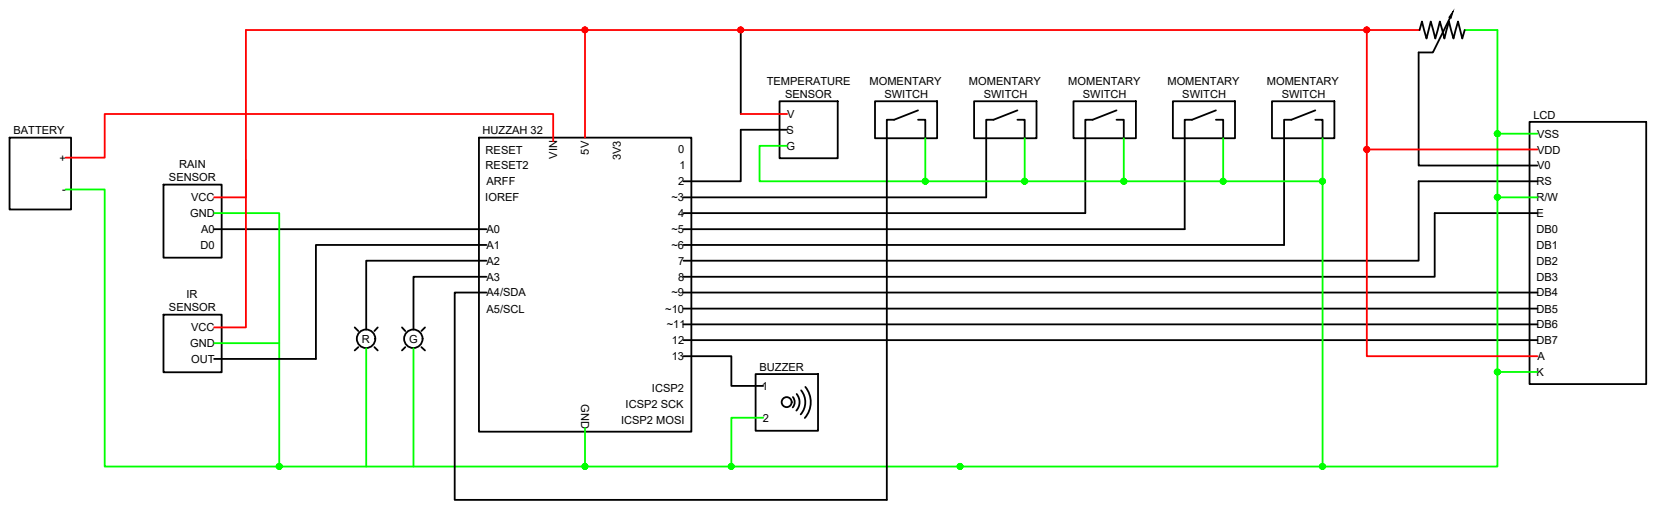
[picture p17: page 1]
VIN GND ~10~9 0 ~11; 41213 ICSP2 MOSI ICSP2 ICSP2 SCK; LCD DB4 DB3 DB2 DB1 DB0 ERSV0VDD VSS DB5 R/WDB6 DB7 A; K BATTERY; HUZZAH 32; 1TEMPERATURE SENSOR G; MOMENTARY SWITCH; MOMENTARY SWITCH RAIN SENSORD0A0 GND VCC IR SENSOR OUT GND VCC

A5/SCL A4/SDA A3A2A1A0 IOREF ARFF RESET2 RESET

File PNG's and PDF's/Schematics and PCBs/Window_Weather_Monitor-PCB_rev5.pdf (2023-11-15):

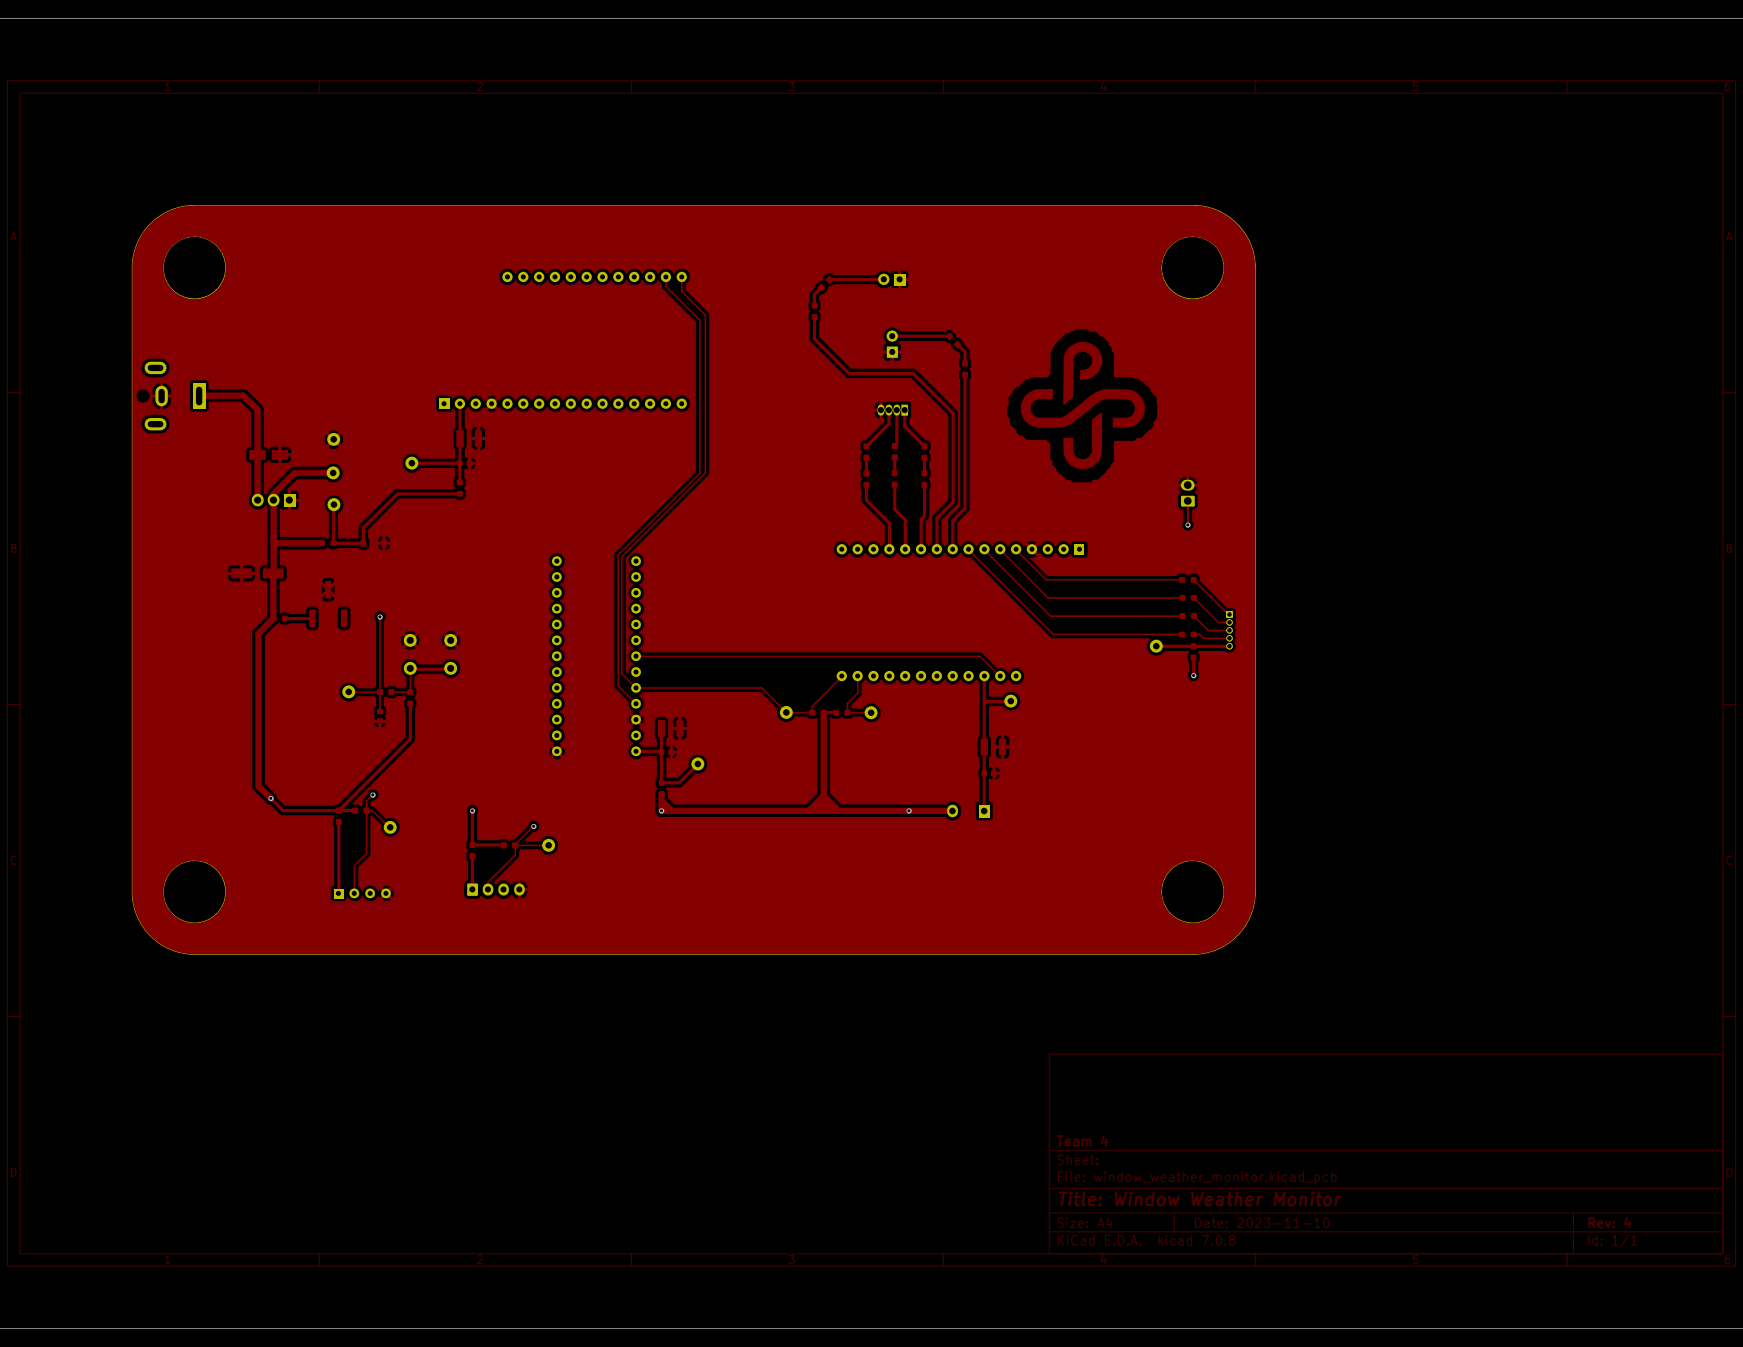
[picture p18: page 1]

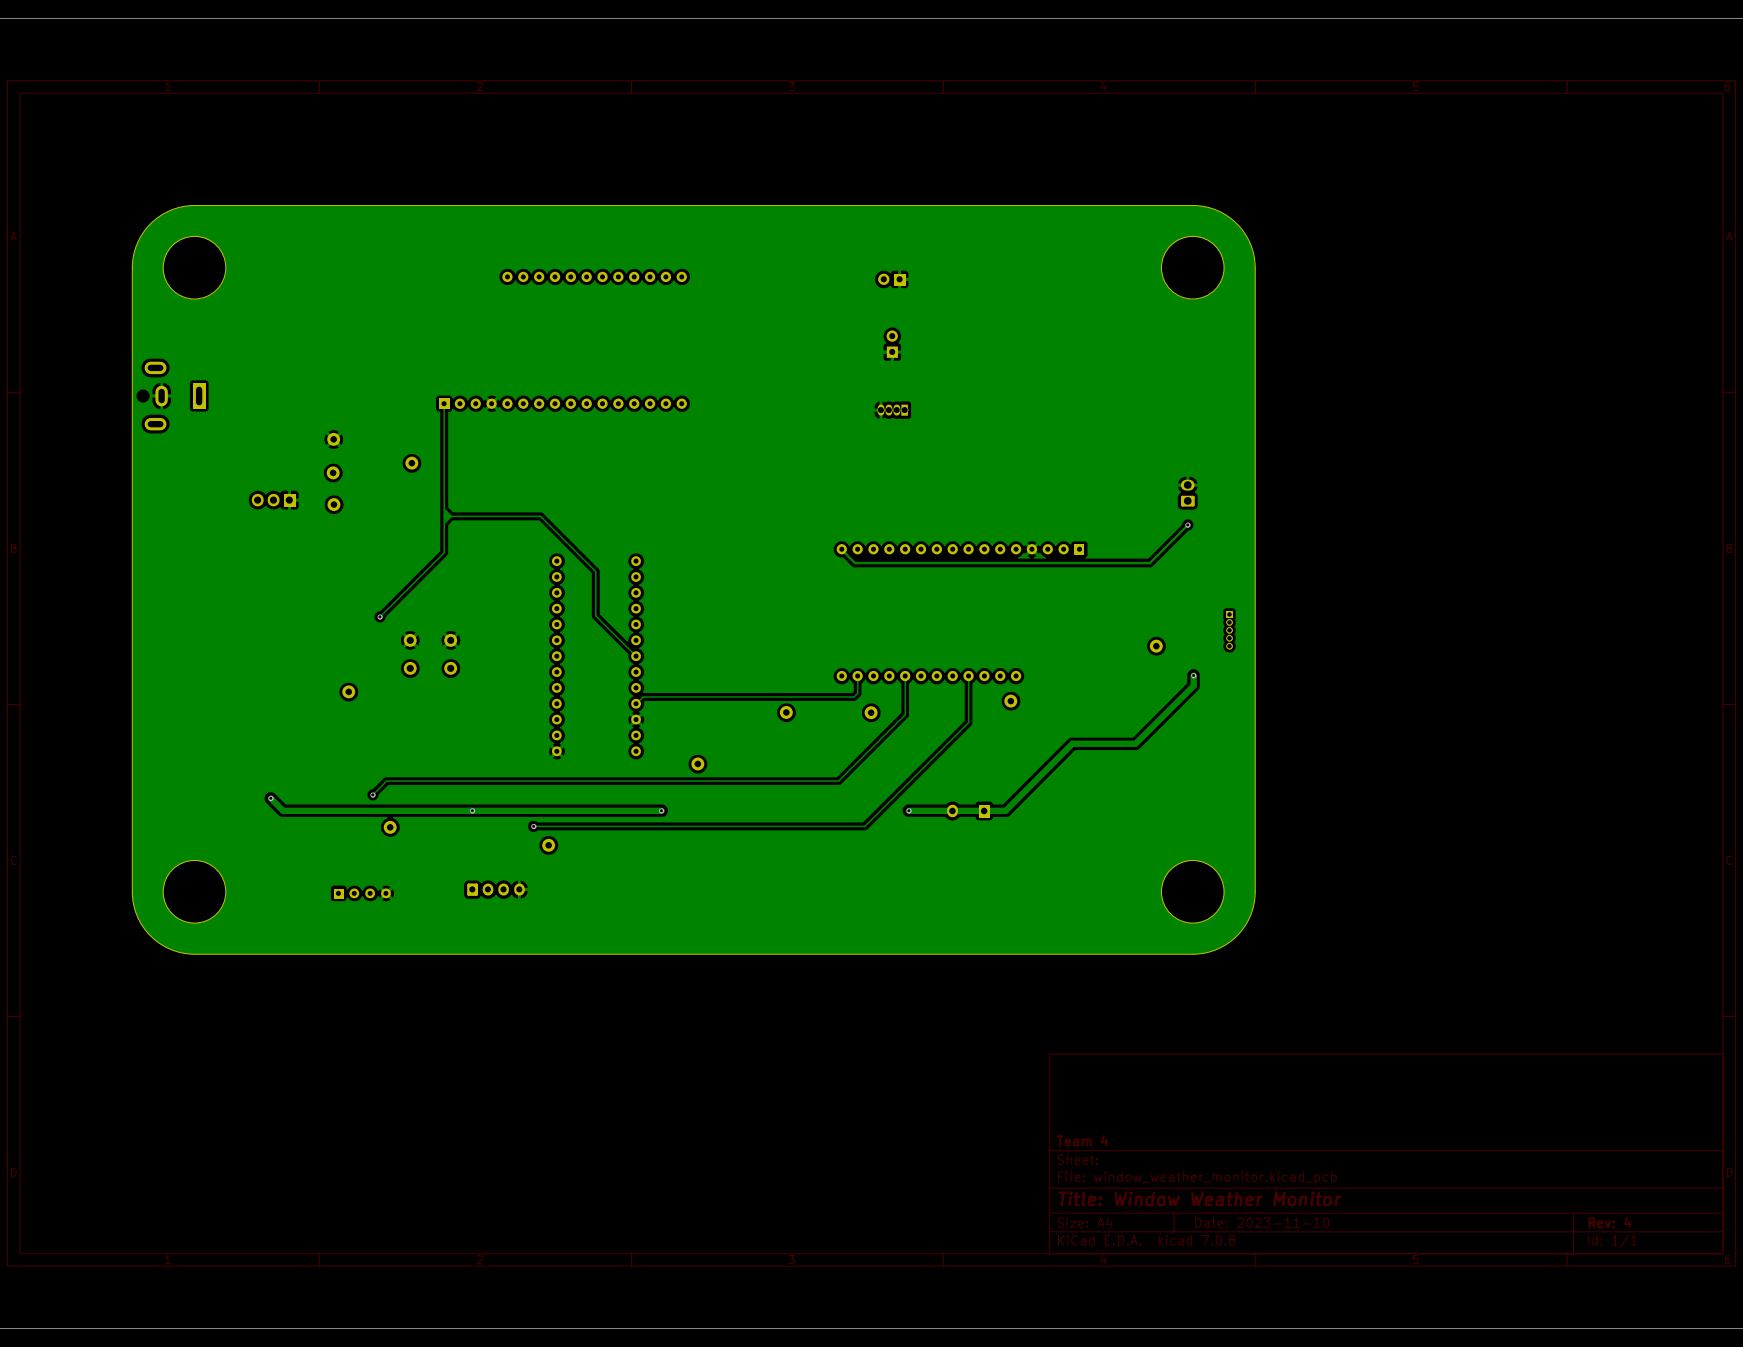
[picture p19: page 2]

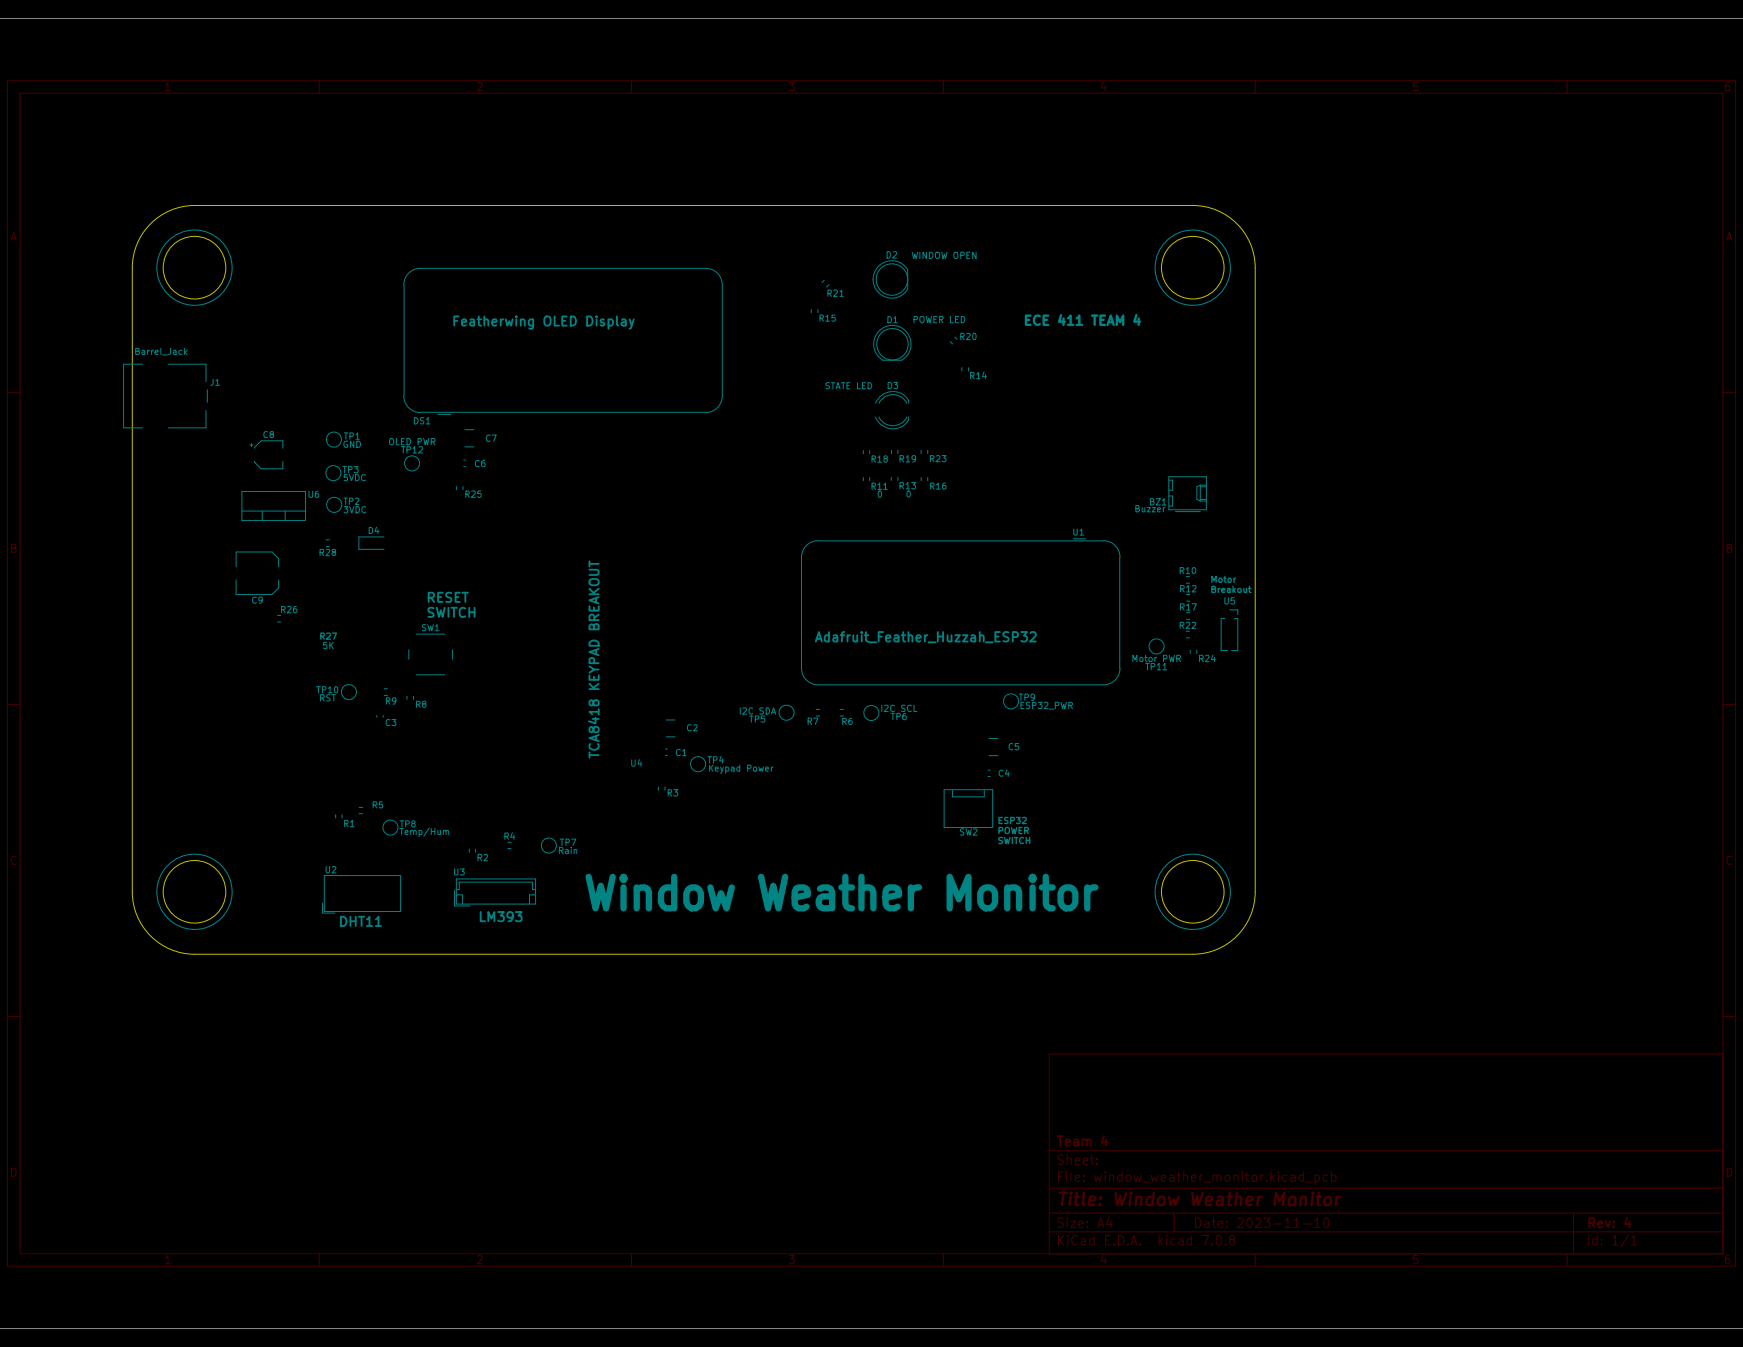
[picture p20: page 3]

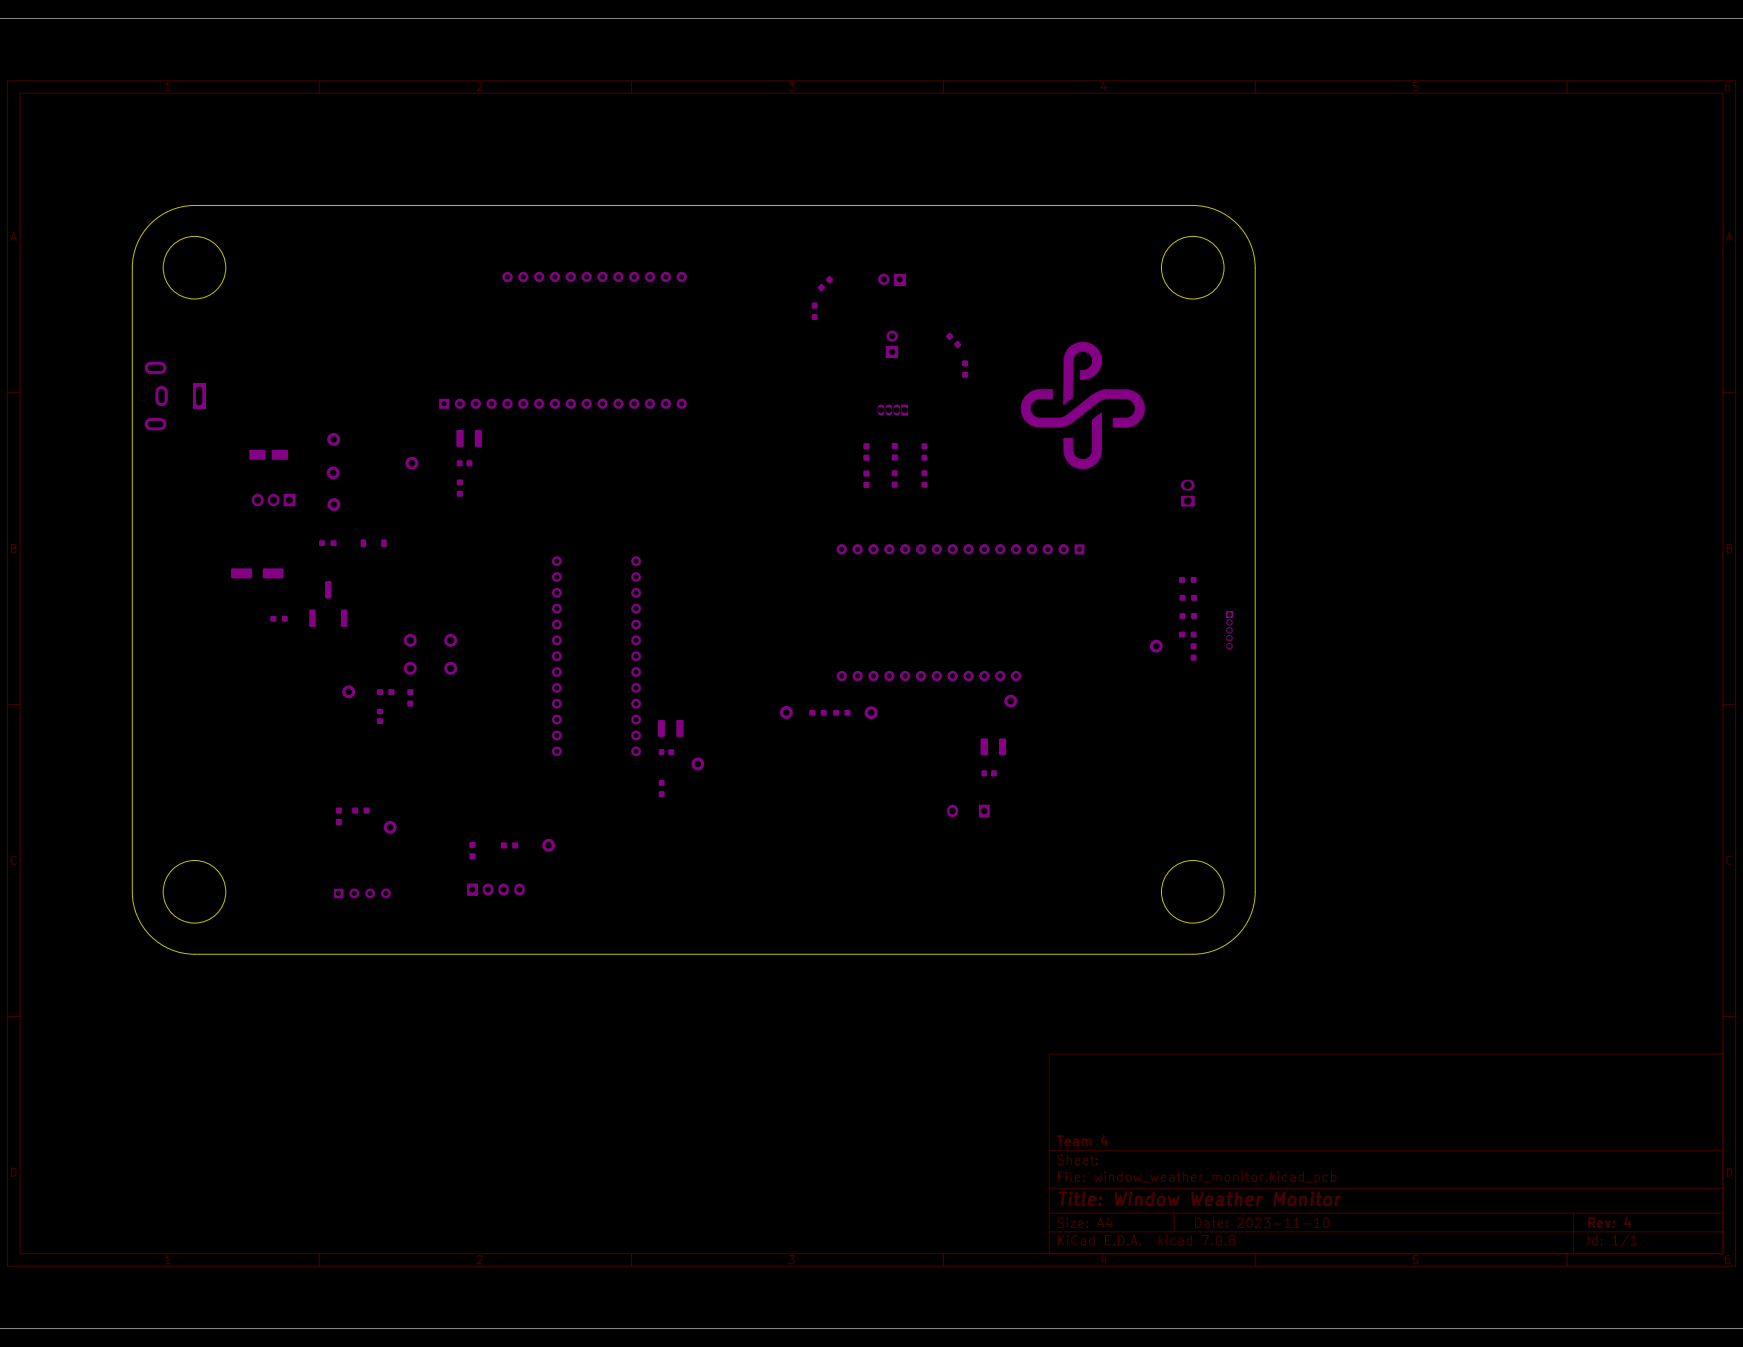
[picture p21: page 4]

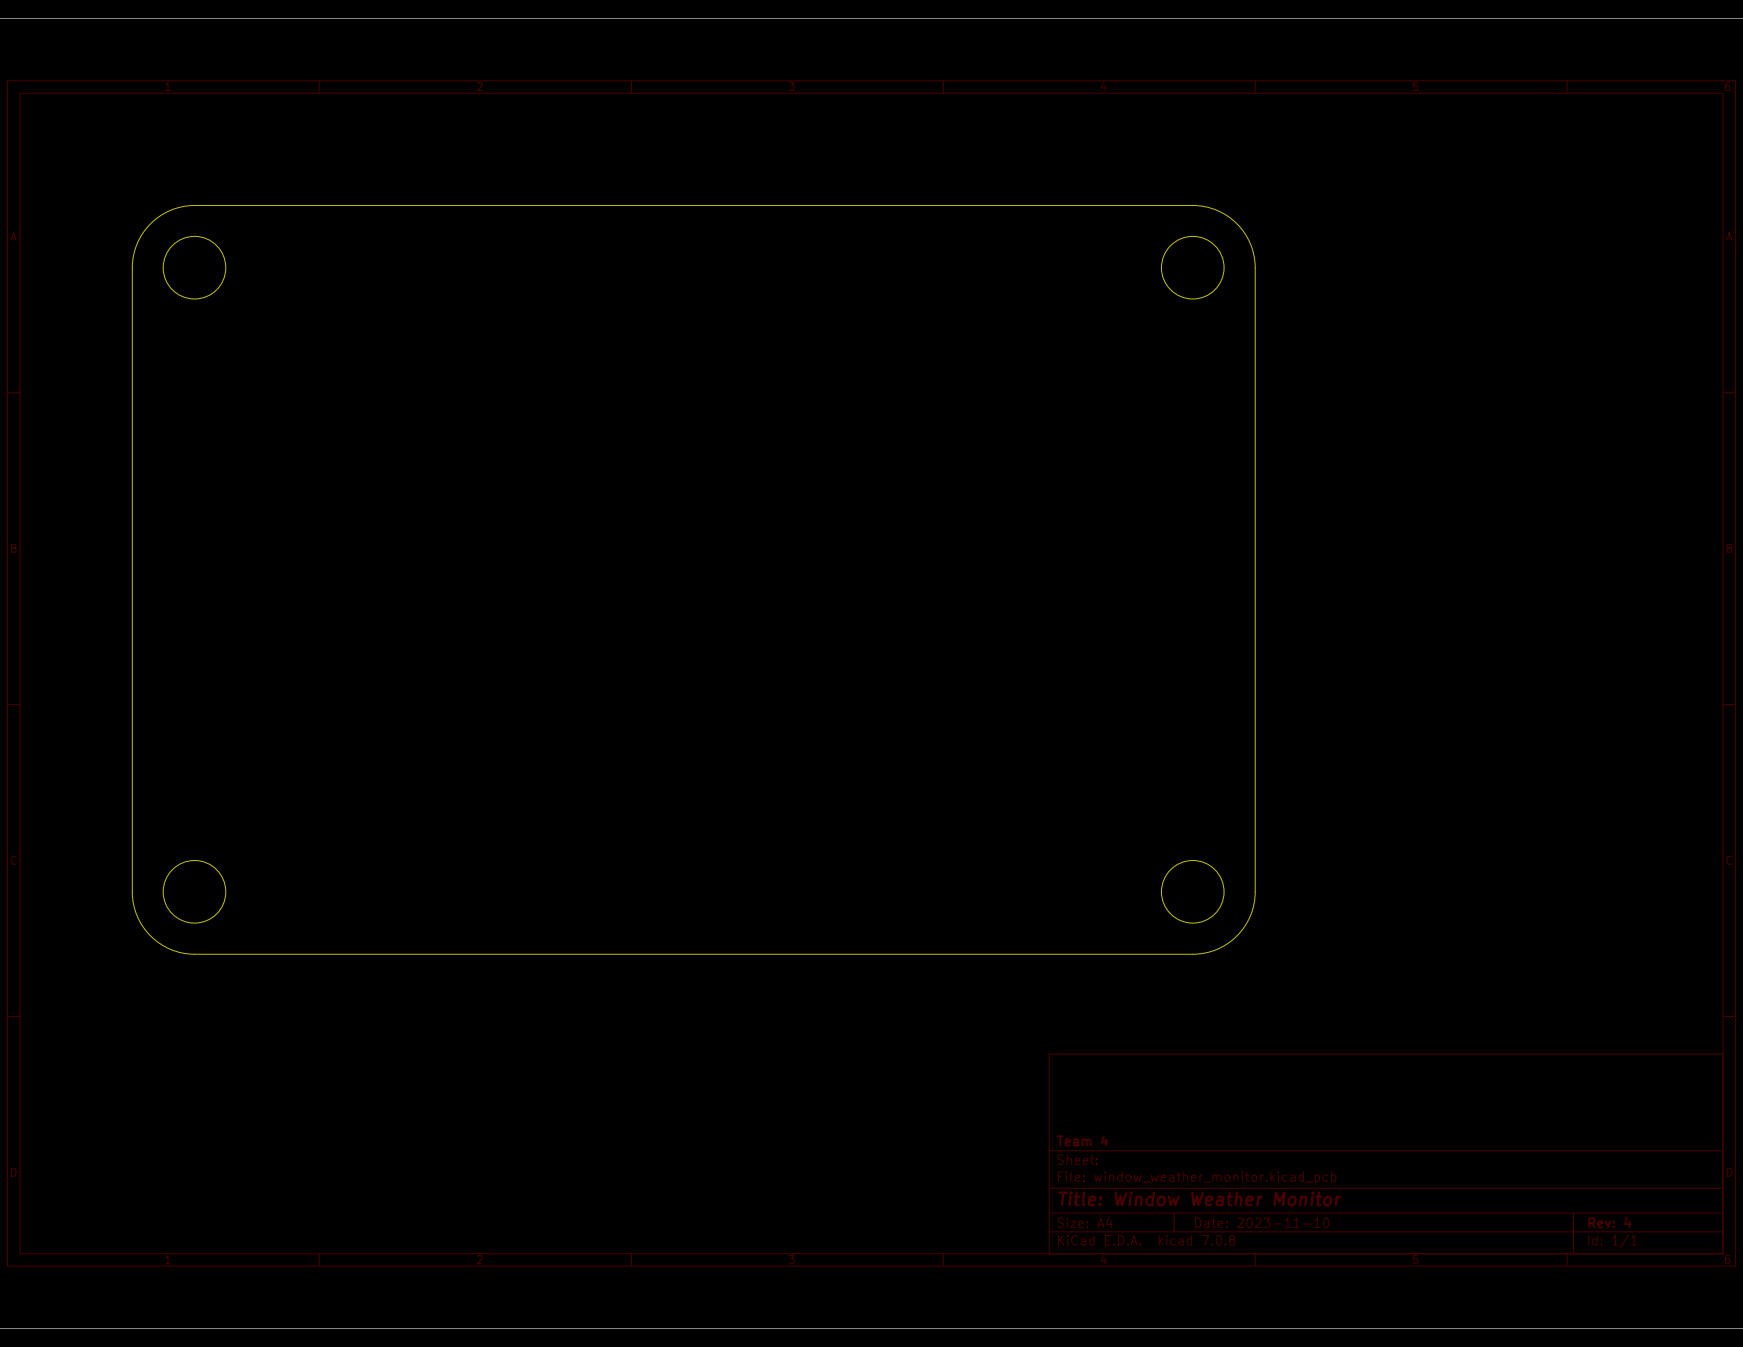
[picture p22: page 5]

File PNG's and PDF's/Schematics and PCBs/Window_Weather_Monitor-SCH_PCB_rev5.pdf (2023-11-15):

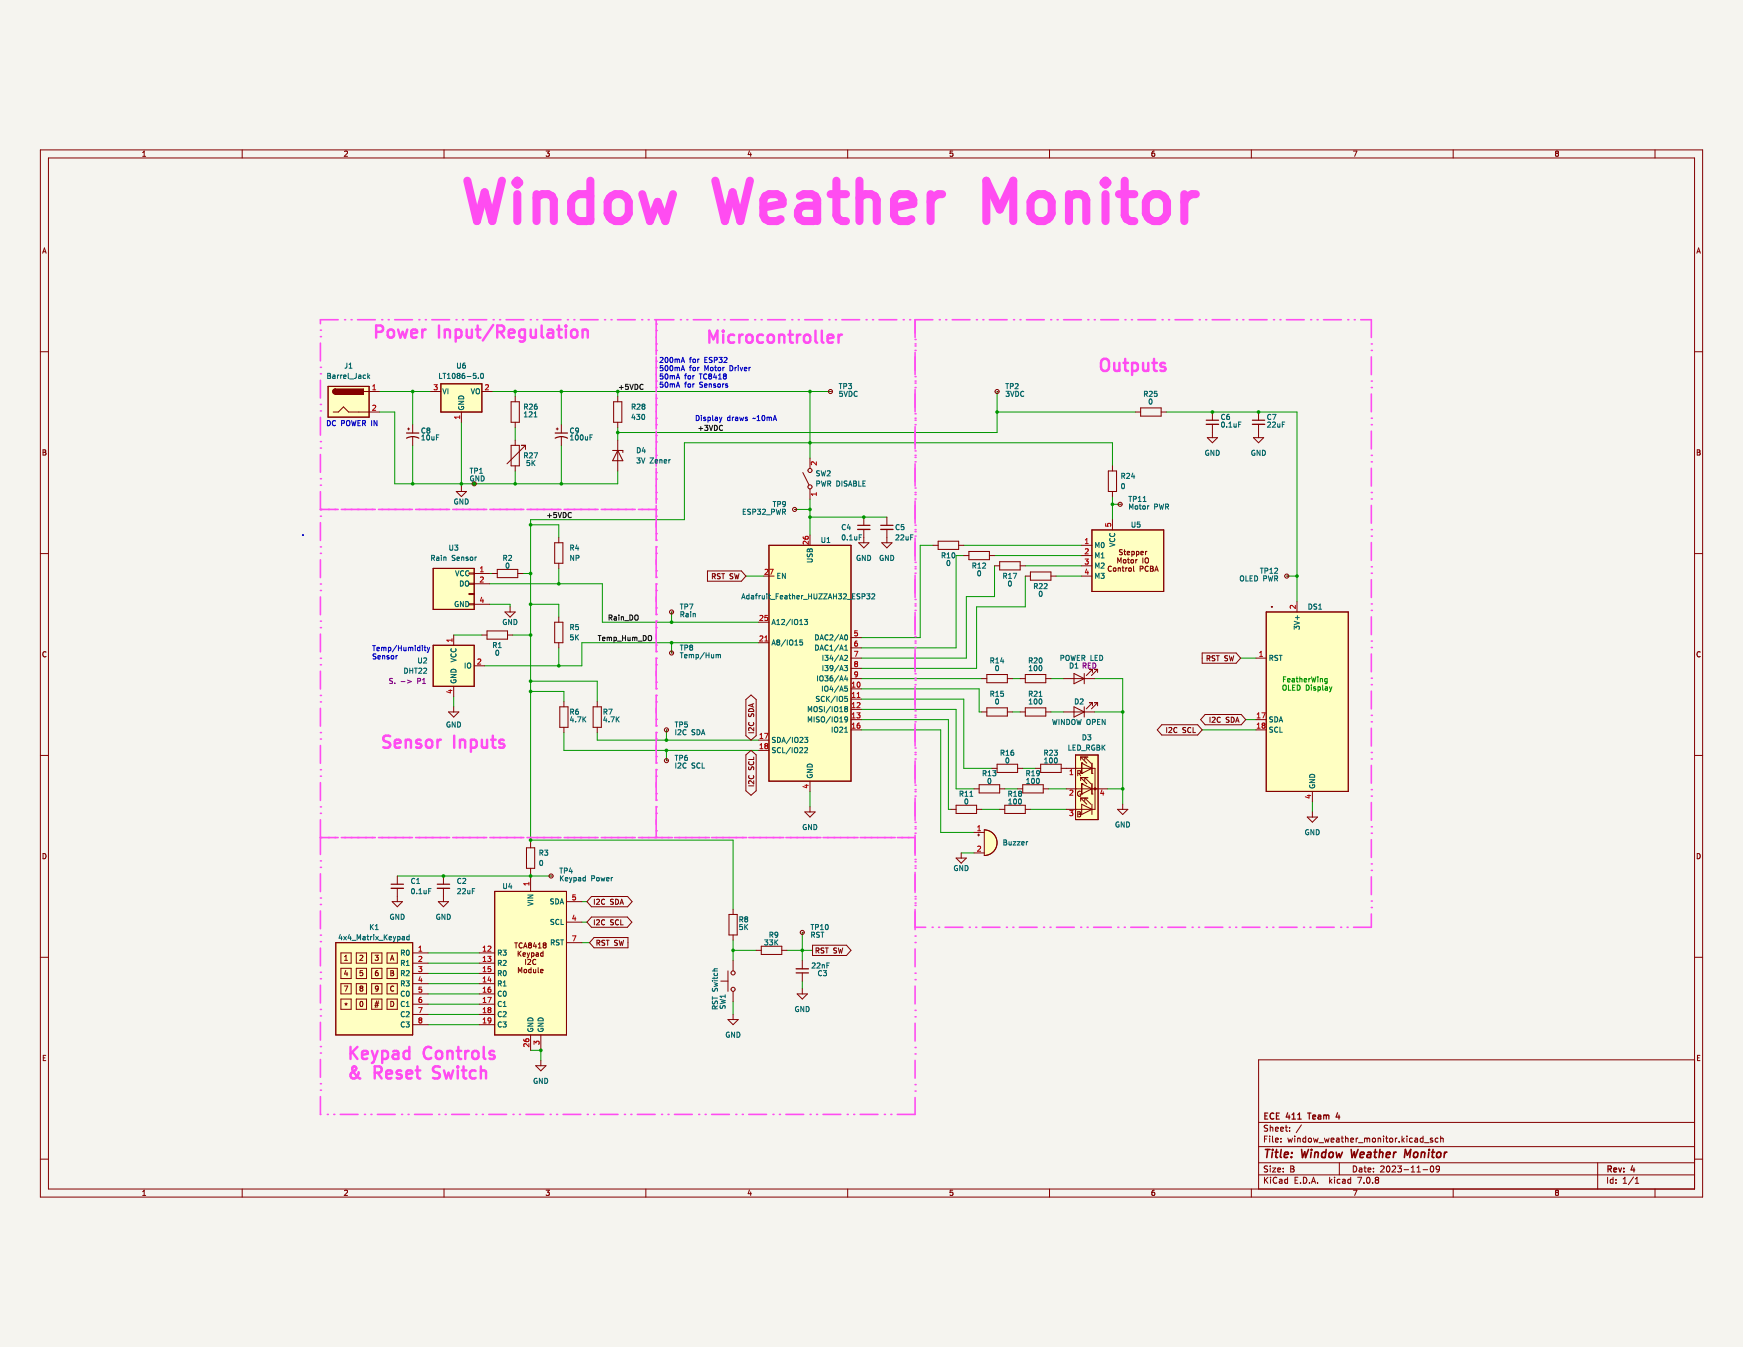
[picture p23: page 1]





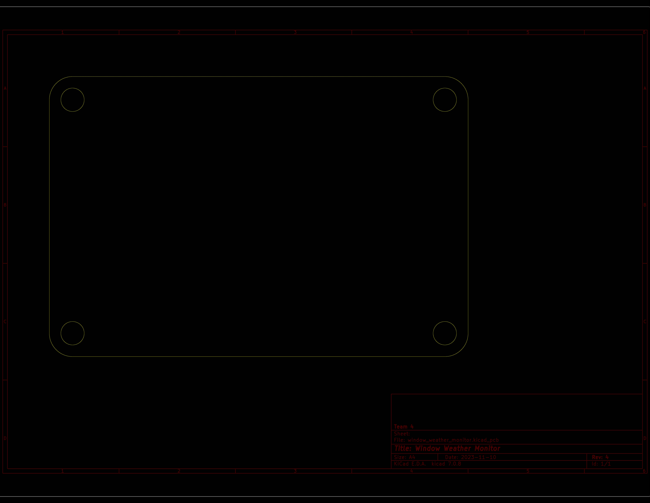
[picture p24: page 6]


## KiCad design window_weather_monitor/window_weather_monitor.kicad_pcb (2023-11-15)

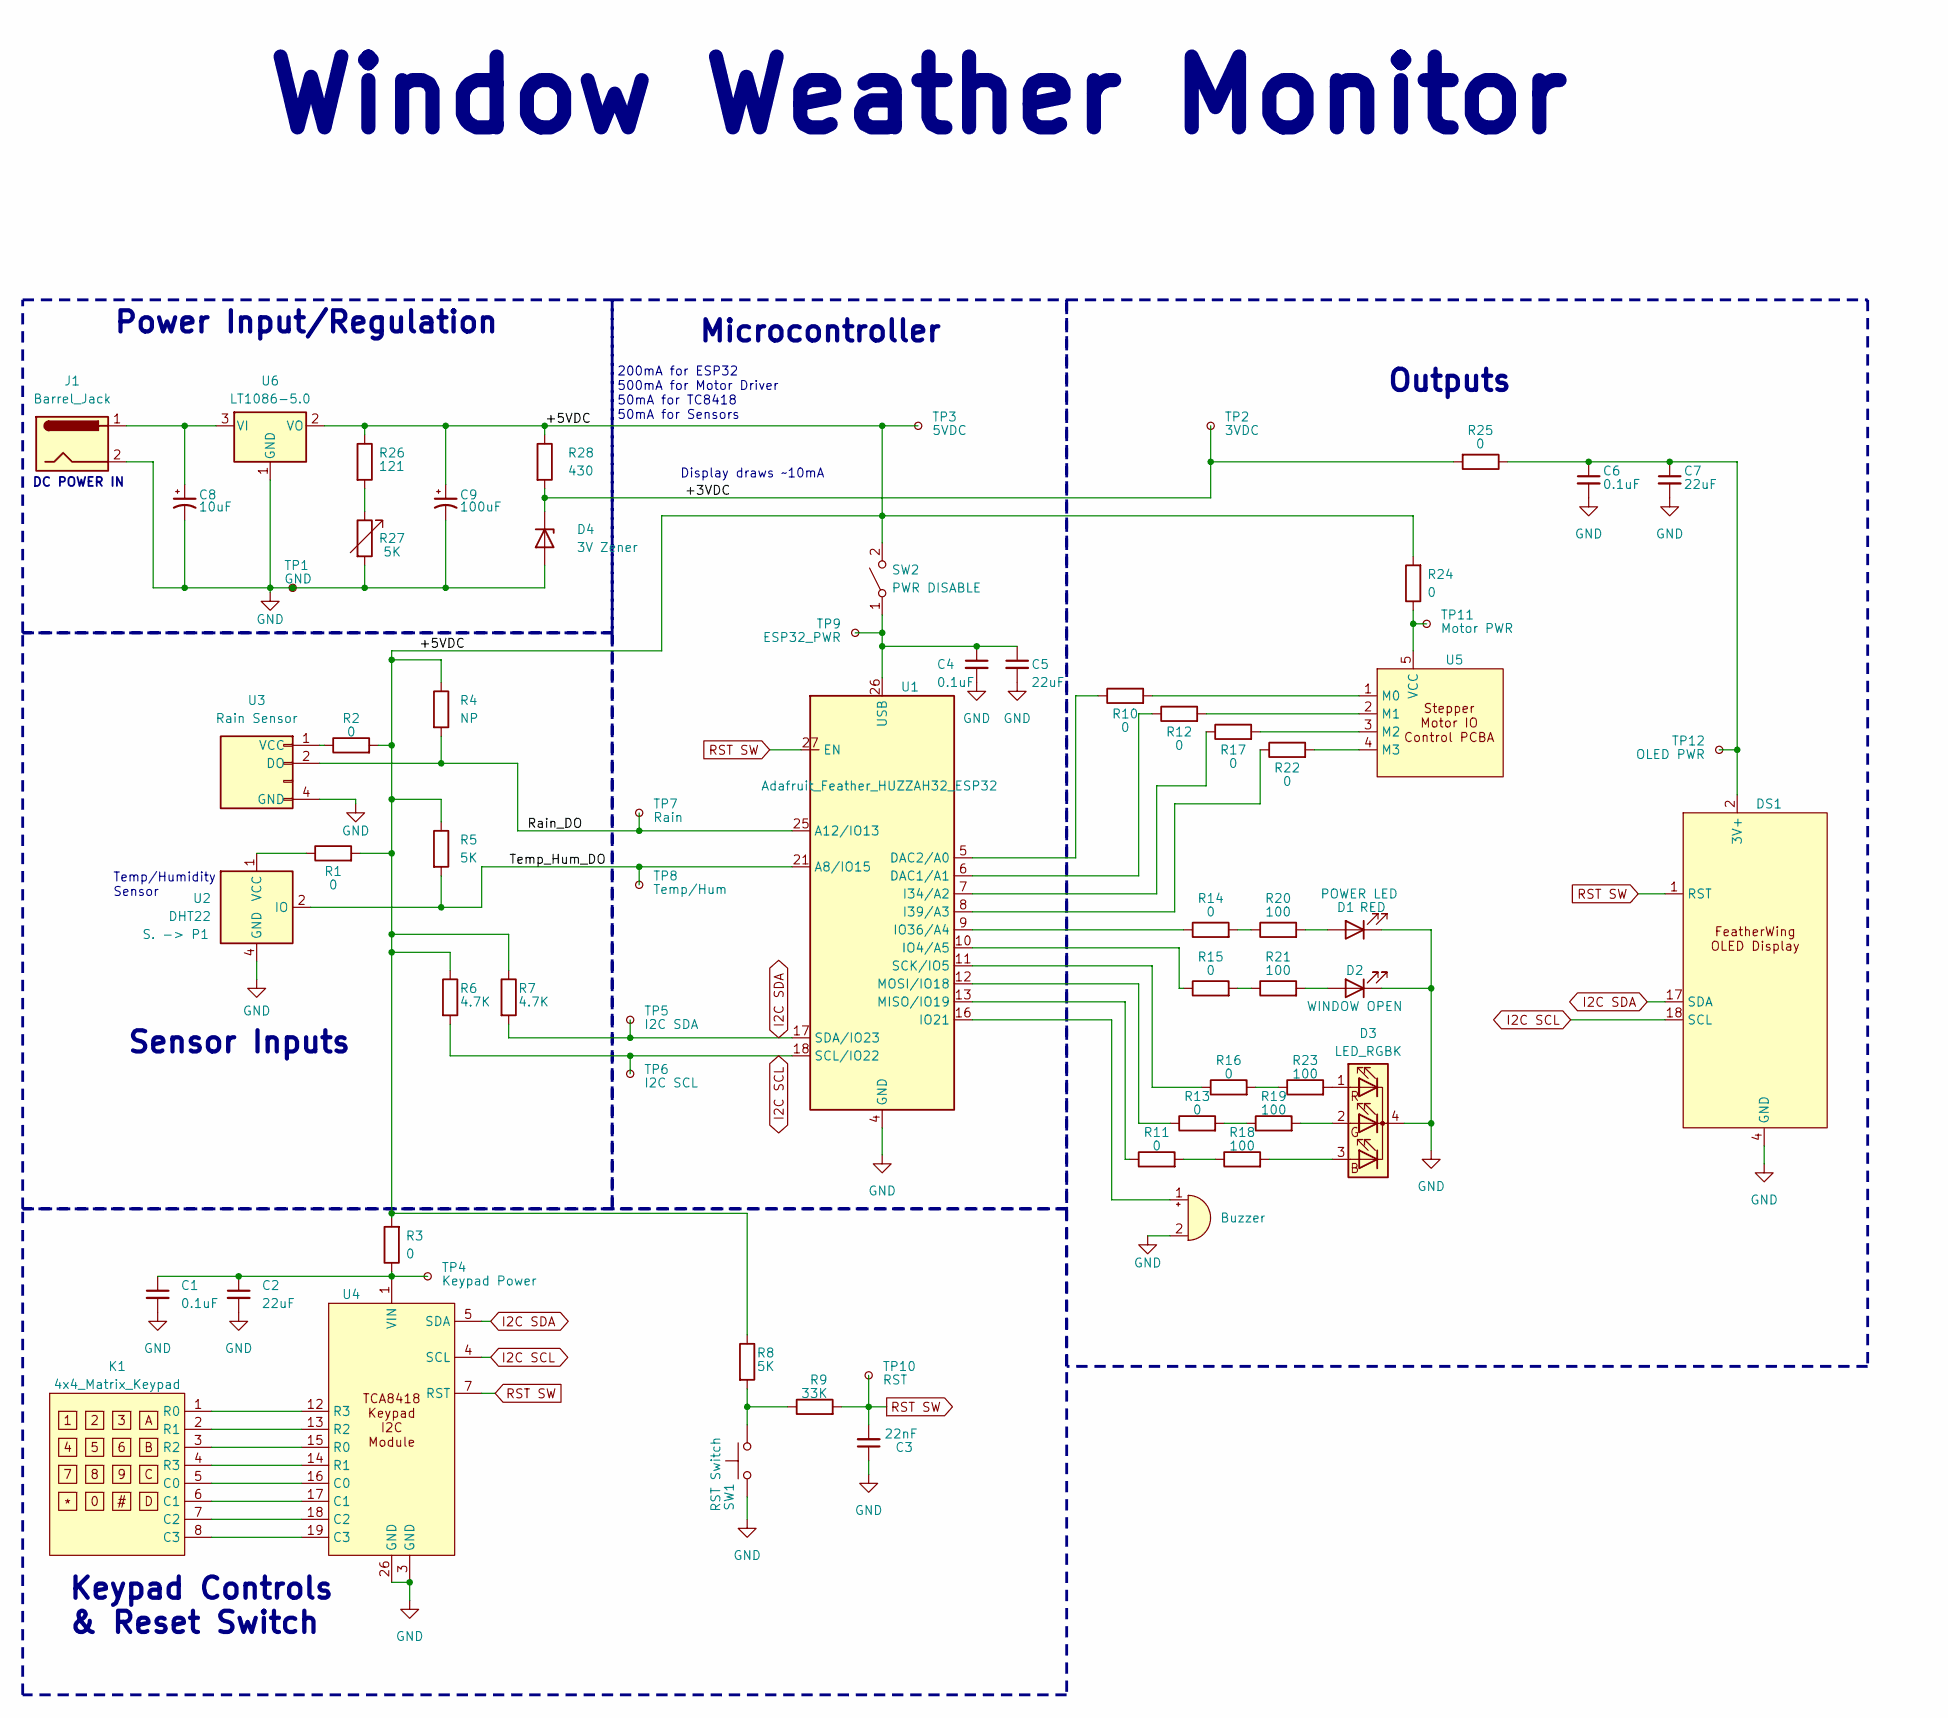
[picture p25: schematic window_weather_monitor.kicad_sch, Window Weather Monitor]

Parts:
BZ1: Buzzer; Molex_KK-254_AE-6410-02A_1x02_P2.54mm_Vertical; MFG PN N/A
C1, C4, C6: 0.1uF; C_0603_1608Metric; MFG PN C0603C104K8RAC7867
C2, C5, C7: 22uF; C_1210_3225Metric; MFG PN CL32B226KPJVPNE
C3: 22nF; C_0603_1608Metric; MFG PN CL05B223KP5NNNC
C8: 10uF; CP_Elec_4x5.4; MFG PN EEE-HA1A101WP
C9: 100uF; C_Elec_6.3x5.8; MFG PN EEE-1CA100SR
D1: POWER LED; LED_D5.0mm; MFG PN MT4118-HR-A
D2: WINDOW OPEN; LED_D5.0mm; MFG PN MT2118-G-A
D3: LED_RGBK; LED_D5.0mm-4_RGB; MFG PN HV-5RGB60
D4: 3V Zener; D_SOD-123; MFG PN MMSZ4684-TP
DS1: Adafruit_Feather; MFG PN 128x4 OLED
J1: Barrel_Jack; BarrelJack_CUI_PJ-063AH_Horizontal; MFG PN PJ-063AH
K1: 4x4_Matrix_Keypad
R1, R2, R3, R10, R11, R12, R13, R14, R15, R16, R17, R22, R24, R25: 0; R_0603_1608Metric_Pad0.98x0.95mm_HandSolder; MFG PN RMCF0603ZT0R00
R4: NP; R_0603_1608Metric_Pad0.98x0.95mm_HandSolder; MFG PN RMCF0603ZT0R00
R5, R8: 5K; R_0603_1608Metric_Pad0.98x0.95mm_HandSolder; MFG PN RT0603BRE075KL
R6, R7: 4.7K; R_0603_1608Metric_Pad0.98x0.95mm_HandSolder; MFG PN RK73B1JTTD472J
R9: 33K; R_0603_1608Metric_Pad0.98x0.95mm_HandSolder; MFG PN RMCF0603FT33K0
R18, R19, R20, R21, R23: 100; R_0603_1608Metric_Pad0.98x0.95mm_HandSolder; MFG PN RMCF0603FT100R
R26: 121; R_0603_1608Metric_Pad0.98x0.95mm_HandSolder; MFG PN RMCF0603FT121R
R27: 5K; 5K Trim Pot; MFG PN 84WR5KLFTR
R28: 430; R_0603_1608Metric_Pad0.98x0.95mm_HandSolder; MFG PN RMCF0603FT430R
SW1: RST Switch; SW_PUSH_6mm; MFG PN DAOKI SPST
SW2: PWR DISABLE; FanPinHeader_1x03_P2.54mm_Vertical; MFG PN TS02CQE
TP1: GND; TestPoint_THTPad_D2.0mm_Drill1.0mm
TP2: 3VDC; TestPoint_THTPad_D2.0mm_Drill1.0mm
TP3: 5VDC; TestPoint_THTPad_D2.0mm_Drill1.0mm
TP4: Keypad Power; TestPoint_THTPad_D2.0mm_Drill1.0mm
TP5: I2C SDA; TestPoint_THTPad_D2.0mm_Drill1.0mm
TP6: I2C SCL; TestPoint_THTPad_D2.0mm_Drill1.0mm
TP7: Rain; TestPoint_THTPad_D2.0mm_Drill1.0mm
TP8: Temp/Hum; TestPoint_THTPad_D2.0mm_Drill1.0mm
TP9: ESP32_PWR; TestPoint_THTPad_D2.0mm_Drill1.0mm
TP10: RST; TestPoint_THTPad_D2.0mm_Drill1.0mm
TP11: Motor PWR; TestPoint_THTPad_D2.0mm_Drill1.0mm
TP12: OLED PWR; TestPoint_THTPad_D2.0mm_Drill1.0mm
U1: Adafruit_Feather_HUZZAH32_ESP32; Adafruit_Feather
U2: DHT22; Aosong_DHT11_5.5x12.0_P2.54mm
U3: Rain Sensor; JST_EH_B4B-EH-A_1x04_P2.50mm_Vertical
U4: TCA8418
U5: PinSocket_1x05_P1.27mm_Vertical
U6: LT1086-5.0; TO-220-3_Vertical; MFG PN LT1086CT#PBF

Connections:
/+3VDC: D4.1 (K), R25.2, R28.2, TP2.1
/+5VDC: C9.1, R1.2, R2.2, R3.2, R4.1, R5.1, R6.1, R7.1, R8.1, R24.2, R26.1, R28.1, SW2.2 (B), TP3.1, U6.2 (VO)
/Rain_DO: R4.2, TP7.1, U1.25 (A12/IO13), U3.2 (DO)
/Temp_Hum_DO: R5.2, TP8.1, U1.21 (A8/IO15), U2.2 (IO)
GND: BZ1.2 (+), C1.2, C2.2, C3.1, C4.2, C5.2, C6.2, C7.2, C8.2, C9.2, D1.1 (K), D2.1 (K), D3.4 (K), D4.2 (A), DS1.4 (GND), J1.2, R27.2, SW1.1, TP1.1, U1.4 (GND), U2.4 (GND), U3.4 (GND), U4.3 (GND), U4.26 (GND), U6.1 (GND)
I2C SCL: DS1.18 (SCL), R6.2, TP6.1, U1.18 (SCL/IO22), U4.4 (SCL)
I2C SDA: DS1.17 (SDA), R7.2, TP5.1, U1.17 (SDA/IO23), U4.5 (SDA)
unnamed: BZ1.1 (-), U1.16 (IO21)
unnamed: D1.2 (A), R20.2
unnamed: D2.2 (A), R21.2
unnamed: D3.3 (BA), R18.2
unnamed: D3.2 (GA), R19.2
unnamed: D3.1 (RA), R23.2
unnamed: C6.1, C7.1, DS1.2 (3V+), R25.1, TP12.1
unnamed: R8.2, R9.1, SW1.2
unnamed: R11.2, R18.1
unnamed: R13.2, R19.1
unnamed: R14.2, R20.1
unnamed: R15.2, R21.1
unnamed: R16.2, R23.1
unnamed: R26.2, R27.1
unnamed: C4.1, C5.1, SW2.1 (A), TP9.1, U1.26 (USB)
unnamed: R12.1, U1.6 (DAC1/A1)
unnamed: R10.1, U1.5 (DAC2/A0)
unnamed: R17.1, U1.7 (I34/A2)
unnamed: R22.1, U1.8 (I39/A3)
unnamed: R15.1, U1.10 (IO4/A5)
unnamed: R14.1, U1.9 (IO36/A4)
unnamed: R11.1, U1.13 (MISO/IO19)
unnamed: R13.1, U1.12 (MOSI/IO18)
unnamed: R16.1, U1.11 (SCK/IO5)
unnamed: R1.1, U2.1 (VCC)
unnamed: R2.1, U3.1 (VCC)
unnamed: K1.5 (C0), U4.16 (C0)
unnamed: K1.6 (C1), U4.17 (C1)
unnamed: K1.7 (C2), U4.18 (C2)
unnamed: K1.8 (C3), U4.19 (C3)
unnamed: K1.3 (R2), U4.15 (R0)
unnamed: K1.4 (R3), U4.14 (R1)
unnamed: K1.2 (R1), U4.13 (R2)
unnamed: K1.1 (R0), U4.12 (R3)
unnamed: C1.1, C2.1, R3.1, TP4.1, U4.1 (VIN)
unnamed: R10.2, U5.1 (M0)
unnamed: R12.2, U5.2 (M1)
unnamed: R17.2, U5.3 (M2)
unnamed: R22.2, U5.4 (M3)
unnamed: R24.1, TP11.1, U5.5 (VCC)
unnamed: C8.1, J1.1, U6.3 (VI)
RST SW: C3.2, DS1.1 (RST), R9.2, TP10.1, U1.27 (EN), U4.7 (RST), U4.9 (R6)

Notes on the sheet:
Keypad Controls & Reset Switch
200mA for ESP32 500mA for Motor Driver 50mA for TC8418 50mA for Sensors
Display draws ~10mA
Microcontroller
Temp/Humidity Sensor
DC POWER IN
Sensor Inputs
Power Input/Regulation
Outputs
Window Weather Monitor

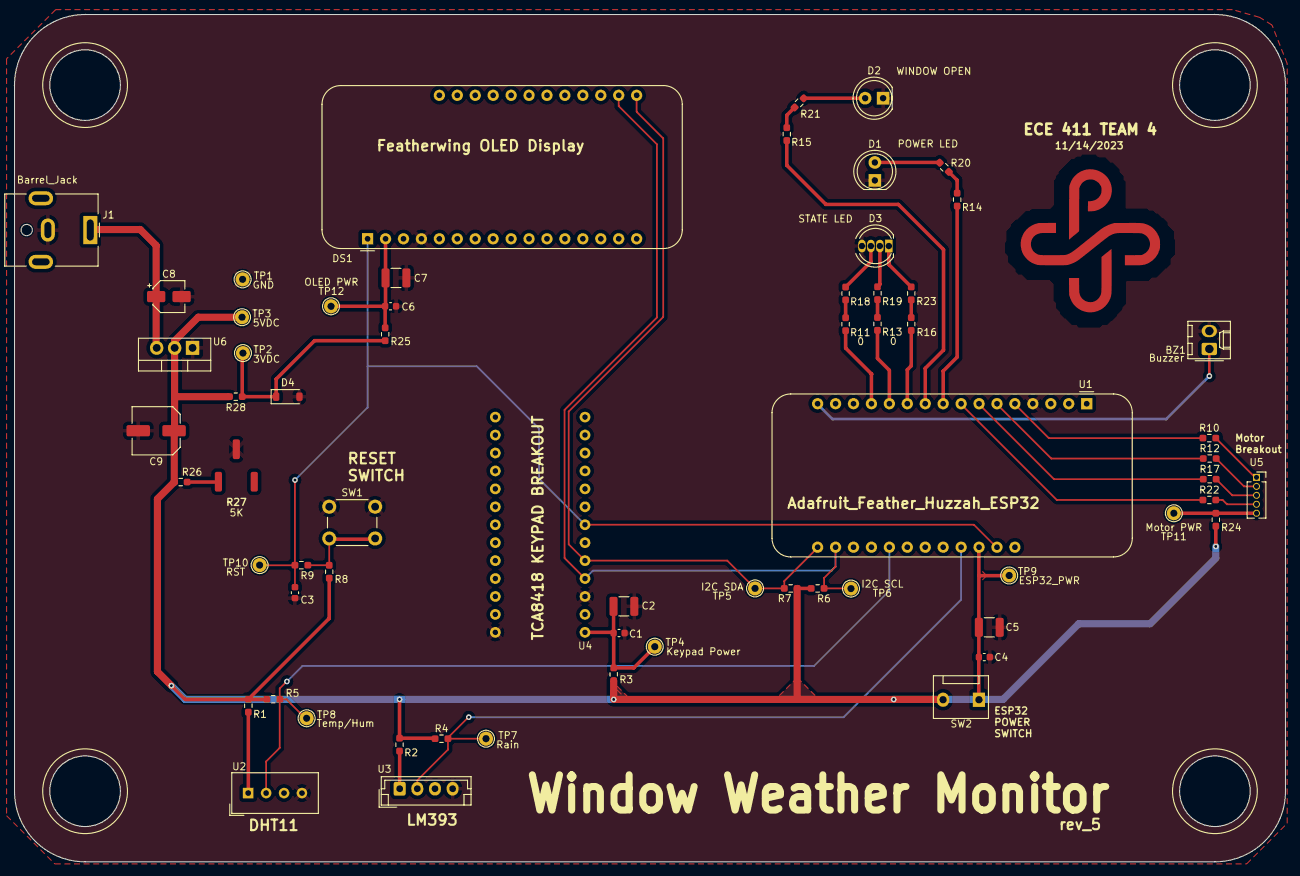
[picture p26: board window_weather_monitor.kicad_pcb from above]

Board: 2 copper layers, 180.0 x 120.0 mm, 65 parts (0 on the bottom side), 41 nets.

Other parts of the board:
Ref**: Val**; PSU_F.Cu

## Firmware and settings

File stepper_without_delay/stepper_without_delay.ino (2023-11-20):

//www.elegoo.com
//2018.10.25

/*
  Stepper Motor Control - one revolution

  This program drives a unipolar or bipolar stepper motor.
  The motor is attached to digital pins 8 - 11 of the Arduino.

  The motor should revolve one revolution in one direction, then
  one revolution in the other direction.

*/

#include <Stepper.h>

const int stepsPerRevolution = 2048;  // change this to fit the number of steps per revolution
const int rolePerMinute = 15;         // Adjustable range of 28BYJ-48 stepper is 0~17 rpm
unsigned long previousMillis = 0;        // will store last time LED was updated
const long interval = 5000;           // interval at which to blink (milliseconds)

// initialize the stepper library on pins 8 through 11:
// For ESP32, pins are 33, 27, 12, 13
Stepper myStepper(stepsPerRevolution, 33, 27, 12, 13);

void setup() {
  myStepper.setSpeed(rolePerMinute);
  // initialize the serial port:
  Serial.begin(9600);
}

void loop() {
    // Check to see if it's time to rotate the stepper motor
  unsigned long currentMillis = millis();

  if (currentMillis - previousMillis >= interval) {
    // Save the last time the motor was rotated
    previousMillis = currentMillis;
} 
// Step one revolution in one direction
    Serial.println("clockwise");
  myStepper.step(stepsPerRevolution);
  
// Step one revolution in the other direction
  Serial.println("counterclockwise");
  myStepper.step(-stepsPerRevolution);
  }

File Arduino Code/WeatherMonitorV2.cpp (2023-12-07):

// Menu.cpp
#include "Menu.h"


// Global pointer to the current menu
extern Menu* current_menu; 


/* Prototype definitions */
// Menu creation functions
void setParentMenu(Menu* parent_menu, Menu& child_menu) {
  child_menu.parent = parent_menu;
}

void addChildMenu(Menu* parent_menu, Menu* child_menu) {
  parent_menu->children.push_back(child_menu);
}

void addFunction(Menu* menu, MenuFunction function) {
  menu->functions.push_back(function);
}

// Menu navigation functions
void scrollUp(Menu &menu) {
  menu.currentSelection--;
  if (menu.currentSelection < 0) {
    menu.currentSelection = menu.choices.size() - 1;
  }
}

void scrollDown(Menu &menu) {
  menu.currentSelection++;
  if (menu.currentSelection >= menu.choices.size()) {
    menu.currentSelection = 0;
  }
}

/**
 * selectOption() - Selects the current option in the menu
 * @param current_menu - The current menu layer
 * 
 * This function checks if the current selection is a function or a submenu.
 * If it is a function for the option selected, it calls the function associated
 * with the current selection.
 * If there is no associated function then it is a submenu, and it changes the current menu
 * to the submenu associated with the current selection.
 * 
 * If the current menu has no parent, then it is the main menu and it will not change the current menu.
 * 
 */
void selectOption(Menu* current_menu) {

  // Check if the current menu exists
  if (current_menu == NULL) {
    Serial.println("No menu selected");
  } 
  else {

    // Check if the current selection has a function associated with it
    if (current_menu->currentSelection < current_menu->functions.size()
    && current_menu->functions[current_menu->currentSelection] != nullptr) {
      // Call the function associated with the current selection
      current_menu->functions[current_menu->currentSelection]();
    }
    // Check if the current selection has a submenu associated with it
    else if (current_menu->currentSelection < current_menu->children.size() 
    && current_menu->children[current_menu->currentSelection] != nullptr) {
      // Change the current menu to the submenu associated with the current selection
      current_menu = current_menu->children[current_menu->currentSelection];
    }
    else {
      Serial.println("No function or submenu associated with current selection");
    }
  }

}


/**
 * @brief Goes back to the parent menu
 * 
 * If the current menu has a parent, then it will change the current menu to the parent menu.
 * If the current menu has no parent, then it is the main menu and it will not change the current menu.
 * 
 */
void back() {
  // Print the fields of the current menu
  //printMenu(*current_menu);

  if (current_menu->parent != NULL) {
    // Inform the user what parent menu they are going back to
    Serial.print("Going back to ");
    Serial.println(current_menu->parent->title);

   // Change the current menu to the parent menu
    current_menu = current_menu->parent;
  }
  else {
    Serial.println("No parent menu");
  }


}


// Menu utility functions
/**
 * printMenuStatus() - Prints the current menu status to the serial monitor
 * @param menu - The current menu layer
 * 
 * This function prints the current menu status to the serial monitor.
 * It prints the menu title, the current selection, and the choices.
 * It also prints a ">" next to the current selection.
 * 
 * The menu passed in has the format:
 * 
 * Menu {
 * String title,
 * vector<String> choices,
 * int currentSelection,
 * Menu* parent,
 * vector<Menu*> children,
 * vector<MenuFunction> functions
 * }
 * 
 * The menu is printed in the following format:
 * 
 * Menu Title: <title>
 * Current Selection: <currentSelection>
 * Choices:
 * <choice 1>
 * <choice 2>
 * ...
 * <choice n>
 * 
 * If the menu passed in is null, then it prints "No menu selected"
 * 
 * 
 */
void printMenuStatus(Menu* menu) {
  if (menu != NULL) {
    Serial.println("Menu Title: " + menu->title);
    Serial.println("Current Selection: " + String(menu->currentSelection));
    Serial.println("Choices:");
    for (int i = 0; i < menu->choices.size(); i++) {
      Serial.print(i == menu->currentSelection ? ">" : " ");
      Serial.println(menu->choices[i]);
    }
  } else {
    Serial.println("No menu selected");
  }
}

void printMenu(Menu menu) {
  Serial.println("Title: " + menu.title);
  Serial.println("Choices:");
  for (const auto& choice : menu.choices) {
    Serial.println("  " + choice);
  }
  Serial.println("Current Selection: " + String(menu.currentSelection));
  if (menu.parent != nullptr) {
    Serial.println("Parent: " + menu.parent->title);
  } else {
    Serial.println("Parent: None");
  }
  Serial.println("Children:");
  for (const auto& child : menu.children) {
    if (child != nullptr) {
      Serial.println("  " + child->title);
    }
  }
  Serial.println("Functions:");
  for (const auto& function : menu.functions) {
    if (function != nullptr) {
      Serial.println("  Function exists");
    } else {
      Serial.println("  No function");
    }
  }
}

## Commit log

2023-10-26 Preliminary Schematic
2023-10-26 Preliminary Schematic
    Updated schematic
2023-10-26 Uploading first major test of Temp sensor
2023-10-26 Updating DHT11 Sketch
    Added debugging print statements and reset timer on 'same value' conditional branch
2023-10-26 Initial photos of breadboard prototype
    Woooo software oriented projects are easy to draft/prototype
2023-11-06 Add files via upload
    This arduino sketch alternates between clockwise and counterclockwise rotation of the stepper motor without using the delay function.
2023-11-06 Uploading PCBA Project File
    This is an updated schematic and includes all of the IO that we have settled on. The layout should be completed within the next couple days. I may also add a few capacitors as needed.
2023-11-08 Moved arduino files into a zip
2023-11-08 Refactored Arduino code using VSC (Visual Studio Code) and included Sinric Pro zip library
2023-11-08 Unzipping files so you can navigate them in Github
    [ONELINE_DIAGRAM.dwg]
2023-11-08 Kicad Project Files
    .zip archive of the Kicad project files.
2023-11-08 Updated Kicad Project Files
2023-11-08 Added BOM
    [window_weather_monitor_BOM.csv]
2023-11-09 BOM Done.
    [Bill of Materials ECE 411.xlsx]
2023-11-09 Update Bill of Materials ECE 411.xlsx
    [Bill of Materials ECE 411.xlsx]
2023-11-09 Updating Folders and Adding New Schematics/Layout
    [ONELINE_DIAGRAM.dwg]
2023-11-09 Moved old dwgs to Archive, updated schematic/layout pdf
2023-11-10 Add files via upload
    Updated to reflect the material shown in Lecture 6 regarding functional decomposition
2023-11-10 Updated BOM
    [window_weather_monitor_BOM.csv, window_weather_monitor_BOM_11-9-23.csv]
2023-11-11 Updated Schematic and PCBA Layout
    This may be our final layout unless we upgrade the power supply.
2023-11-11 Last Update Layout
    Updated Schematic/Layout/BOM/Project Archive
    [window_weather_monitor_BOM_11_10_23.csv]
2023-11-11 Here's a fun picture of the PCB
2023-11-11 Slight change to footprints on PCB.
    Not going to change the pdf for now. This is only critical for fab.
2023-11-12 Update to Schematic and Layout
    Added new VReg circuit
    [window_weather_monitor_BOM_11_10_23.csv, window_weather_monitor_BOM_11_11_23.csv]
2023-11-13 Updating BOM and Project File
    Project File update renames A1 to U1
    [Bill of Materials ECE 411.xlsx, window_weather_monitor_BOM_11_11_23.csv, window_weather_monitor_BOM_11_13_2023.csv]
2023-11-13 Updated Schematic and PCBA
    Barrel Jack was in odd placement on board.
2023-11-13 Update Bill of Materials ECE 411.xlsx
    Updated BOM to latest values
    [Bill of Materials ECE 411.xlsx]
2023-11-13 Updated PCBA
    Now with more silkscreen!
    I swear I'm done updating this, for now.
2023-11-14 Unzipped Kicad project file
    I did this to make the files more accessible on Git
    [window_weather_monitor.kicad_pcb, window_weather_monitor.kicad_sch]
2023-11-14 Schematic Update
    It's another schematic update!!
    Removed quotes around title blocks
    Reprinted schematic and combined pdfs
2023-11-15 Updated PCB
    Updated the schematic, layout, generated gerber files for fab, added requisite info on PCB.
    [window_weather_monitor-B_Cu.gbr, window_weather_monitor-B_Mask.gbr, window_weather_monitor-B_Silkscreen.gbr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]
2023-11-16 Update ece411-t04-window-weather-monitor-pcb.zip
    Final update before upload to fab. Small changes after DRC check revealed some nets were off.
2023-11-16 Receipt for PCBA from OSHPark
2023-11-23 Update Bill of Materials ECE 411.xlsx
    added received/received qty/value columns to BOM. Updated to parts we have at Josh's house.
    [Bill of Materials ECE 411.xlsx]
2023-11-23 I found the bug. I deleted the menu passed into select option. instead of checking if menu == NULL, i was setting menu = NULL. (Killing the subsequent code)
    [WeatherMonitorV2.cpp]
2023-11-23 Update to BOM
    updated if parts were received
    [Bill of Materials ECE 411.xlsx]
2023-11-30 Updated Testing functions, added more info, moved pin declarations to own section
2023-12-01 Working menu, Can update user settings, Found issues with pinouts
    [WeatherMonitorV2.cpp]
2023-12-02 Working Keypad menu, I2C display doesn't seem to be working. (Initializes, but no visual output)
    [WeatherMonitorV2.cpp]
2023-12-05 Resolved OLED display issue, was using the SH librarby when I should have been using the SSD library.
    [WeatherMonitorV2.cpp]
2023-12-05 Printing menu on I2C, currently goes offscreen
2023-12-05 Working menu navigation over I2C (Serial input), need to add print messages telling the user what to do (over I2C).
2023-12-06 Adjusted some menu strings, added software reset functionality, modified draw graph(still needs work) added more prototypes & TODO items
    [WeatherMonitorV2.cpp]
